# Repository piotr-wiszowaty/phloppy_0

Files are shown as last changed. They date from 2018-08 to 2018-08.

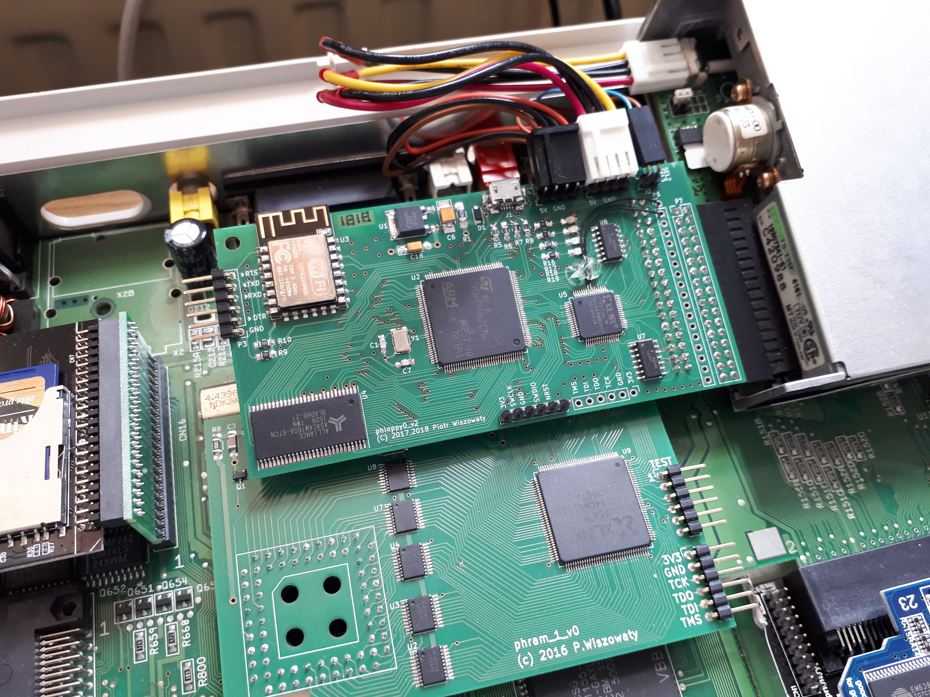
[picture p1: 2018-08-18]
photos/on_floppy.jpg

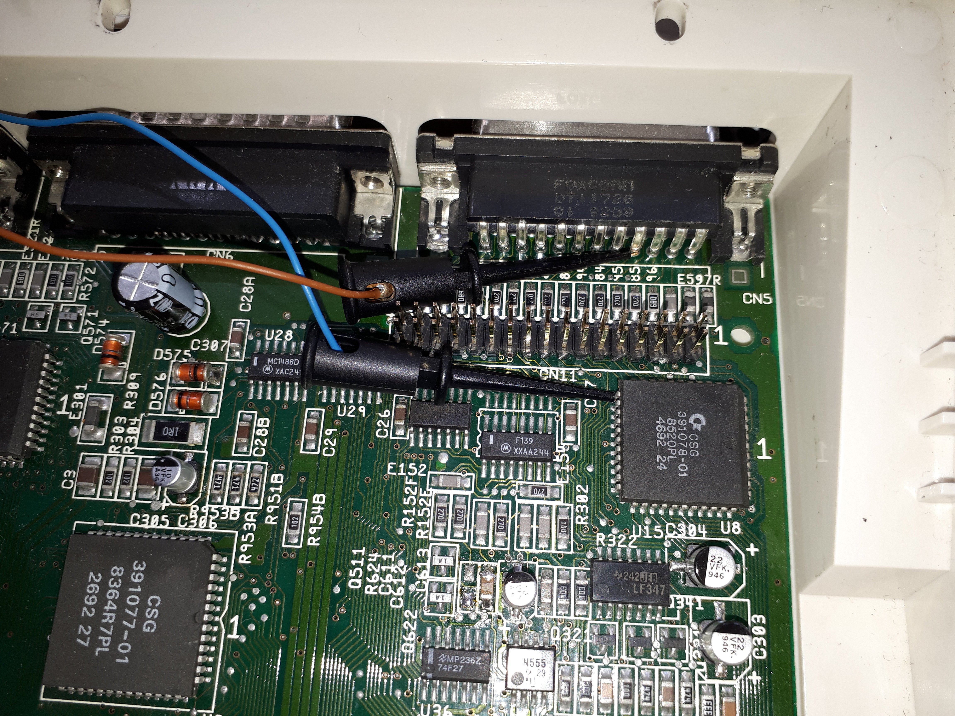
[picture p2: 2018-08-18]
photos/sel2_sel3_a.jpg

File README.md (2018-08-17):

phloppy\_0
=========

phloppy\_0 is a [Commodore Amiga](https://en.wikipedia.org/wiki/Amiga) floppy
drive emulator. It emulates four drives (`DF0:`, `DF1:`, `DF2:`, `DF3:`) and
is controlled through WiFi by an Android or a PC application.

`DF0:` - `DF3:` interoperation
--------------------------

The device is connected between the Amiga motherboard and the internal floppy
drive (DF0:). When a floppy image is inserted in the virtual DF0: the physical
drive input signals `SEL0` and `MTR0` are inactive. When there is no floppy image
in the virtual DF0: the `SEL0` and `MTR0` signals are passed from the Amiga
motherboard through the emulator to the physical drive.

When there are `DF1:` - `DF3`: physical drives connected to the Amiga, inserting
a floppy image in any of the virtual `DF1:` - `DF3:` will result in malfunction
of the drive.

Supported floppy image formats
------------------------------
 
Two floppy image formats are supported:
- ADF ([Amiga Disk File](https://en.wikipedia.org/wiki/Amiga\_Disk\_File)), 880 kB
- raw MFM - 12668 bytes per track, 160 tracks per disk

Hardware
--------

Main hardware components:
- STM32F446 - Cortex-M4 microcontroller; core of the emulator
- SDRAM, 8 MB; used for keeping floppy image contents
- ESP12-E - ESP8266 based WiFi module; provides WiFi hotspot to allow connection
  of a controlling application
- XC9272XL CPLD & two 8-channel open-drain buffers - interface between the
  microcontroller and the Amiga motherboard

On-board connectors:
- micro USB - for flashing the microcontroller
- SWD - for flashing/debugging the microcontroller
- JTAG - for flashing the CPLD
- UART (3.3 V) - for flashing the ESP8266
- power input - from the Amiga motherboard
- power output - to the physical floppy drive
- SEL2, SEL3 - input for the appropriate floppy selection signals
- male 34-pin pinheader - for connecting through a ribbon cable with
  the Amiga motherboard; for A600 the cable should be around 155 mm long
- female 34-pin pinheader - for connecting directly to the physical floppy
  drive

LEDs:
- green - indicates SDRAM active
- yellow - indicates read operation in progress
- red - indicates communication with the controlling application
  in progress
- blue - indicates write buffer is not empty (turn on the controlling
  application to write the buffer to the persistent memory)

In idle mode the device consumes around 170 mA. When the SDRAM is in active
mode the current consumption is around 185 mA.

Software
--------

Software components:
- `android/` - Android control application sources
- `cpld/` - CPLD design files
- `output/` - APK, JED, Gerbers, microcontroller firmware
- `pc/` - PC control application sources
- `uc/` - microcontroller firmware sources
- `wifi/` - ESP8266 source files

The Android application requires SDK level 15 and works at least on
Android 4.0.3 and 8.0.0.

The WiFi hotspot parameters are stored in the STM32 microcontroller and
read by ESP8266 during initialization. The parameters can be changed in source
code or after compilation in the microcontroller firmware image file.

License
-------

The project is licensed under GPL-3.0 license. See `LICENSE` for more information.
Parts of the project are covered by other licenses (see appropriate files for details):
- ESP8266 SPI driver by David Ogilvy (MetalPhreak)
- CMSIS header files by ARM LIMITED
- STM32 header files by STMicroelectronics

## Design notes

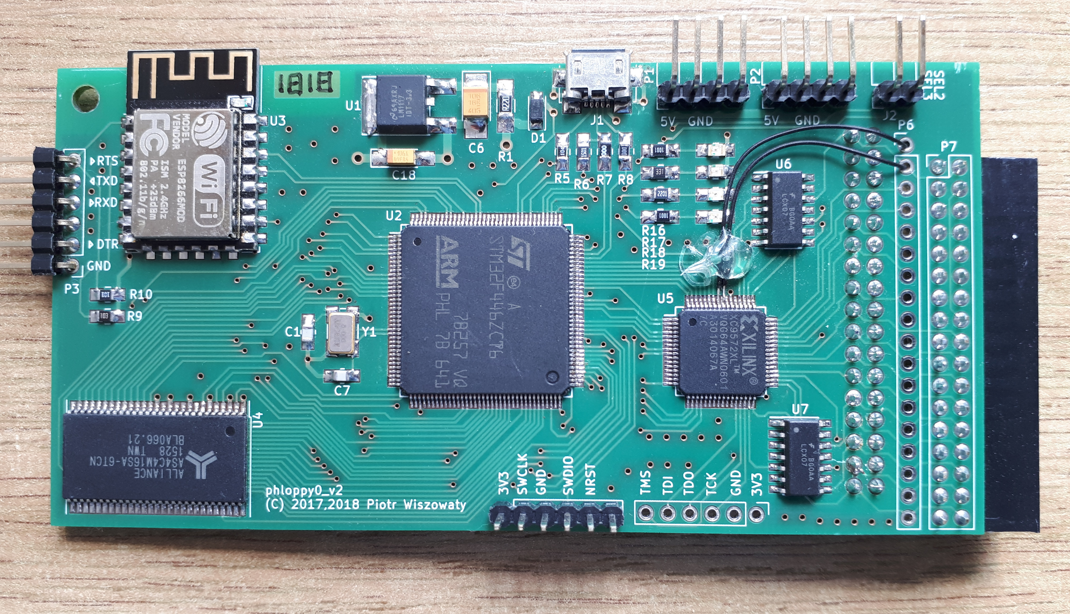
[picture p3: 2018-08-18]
photos/top.jpg

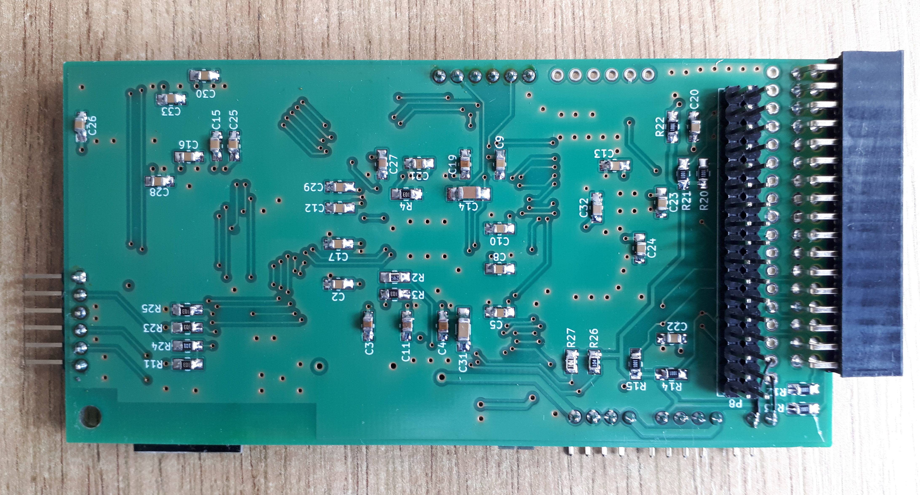
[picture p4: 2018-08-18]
photos/bottom.jpg

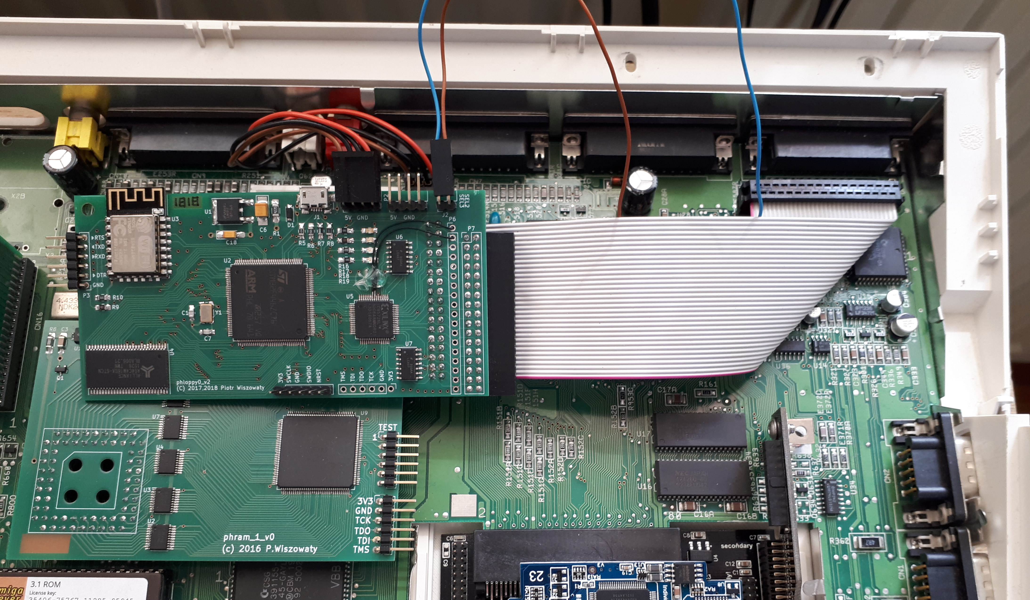
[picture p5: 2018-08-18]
photos/no_floppy.jpg

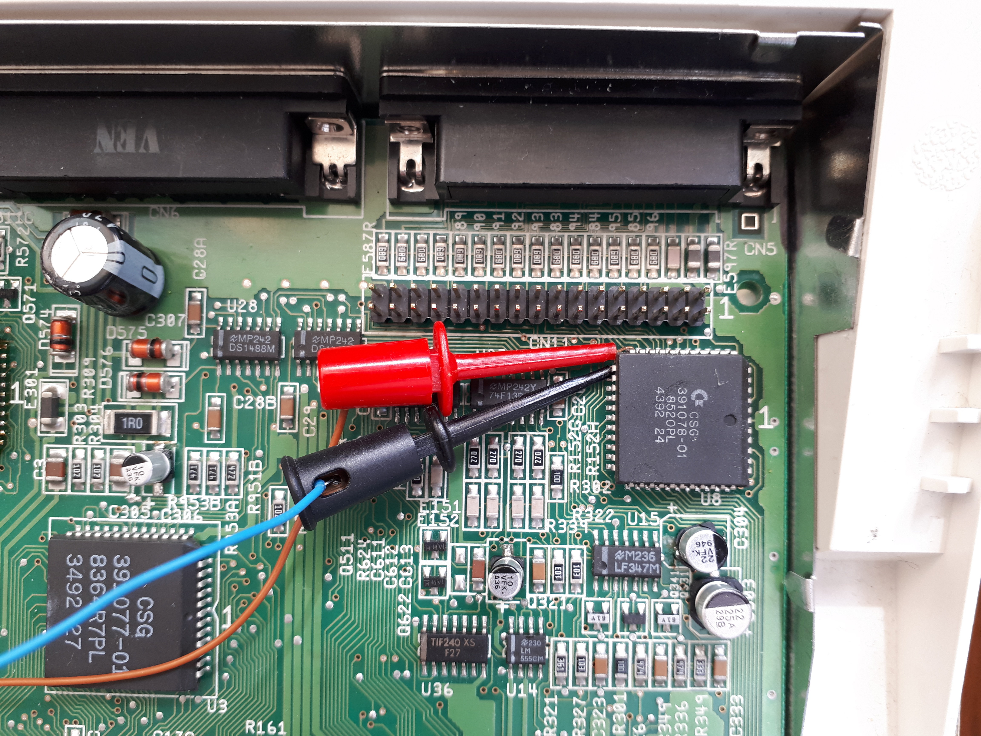
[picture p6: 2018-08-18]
photos/sel2_sel3_b.jpg

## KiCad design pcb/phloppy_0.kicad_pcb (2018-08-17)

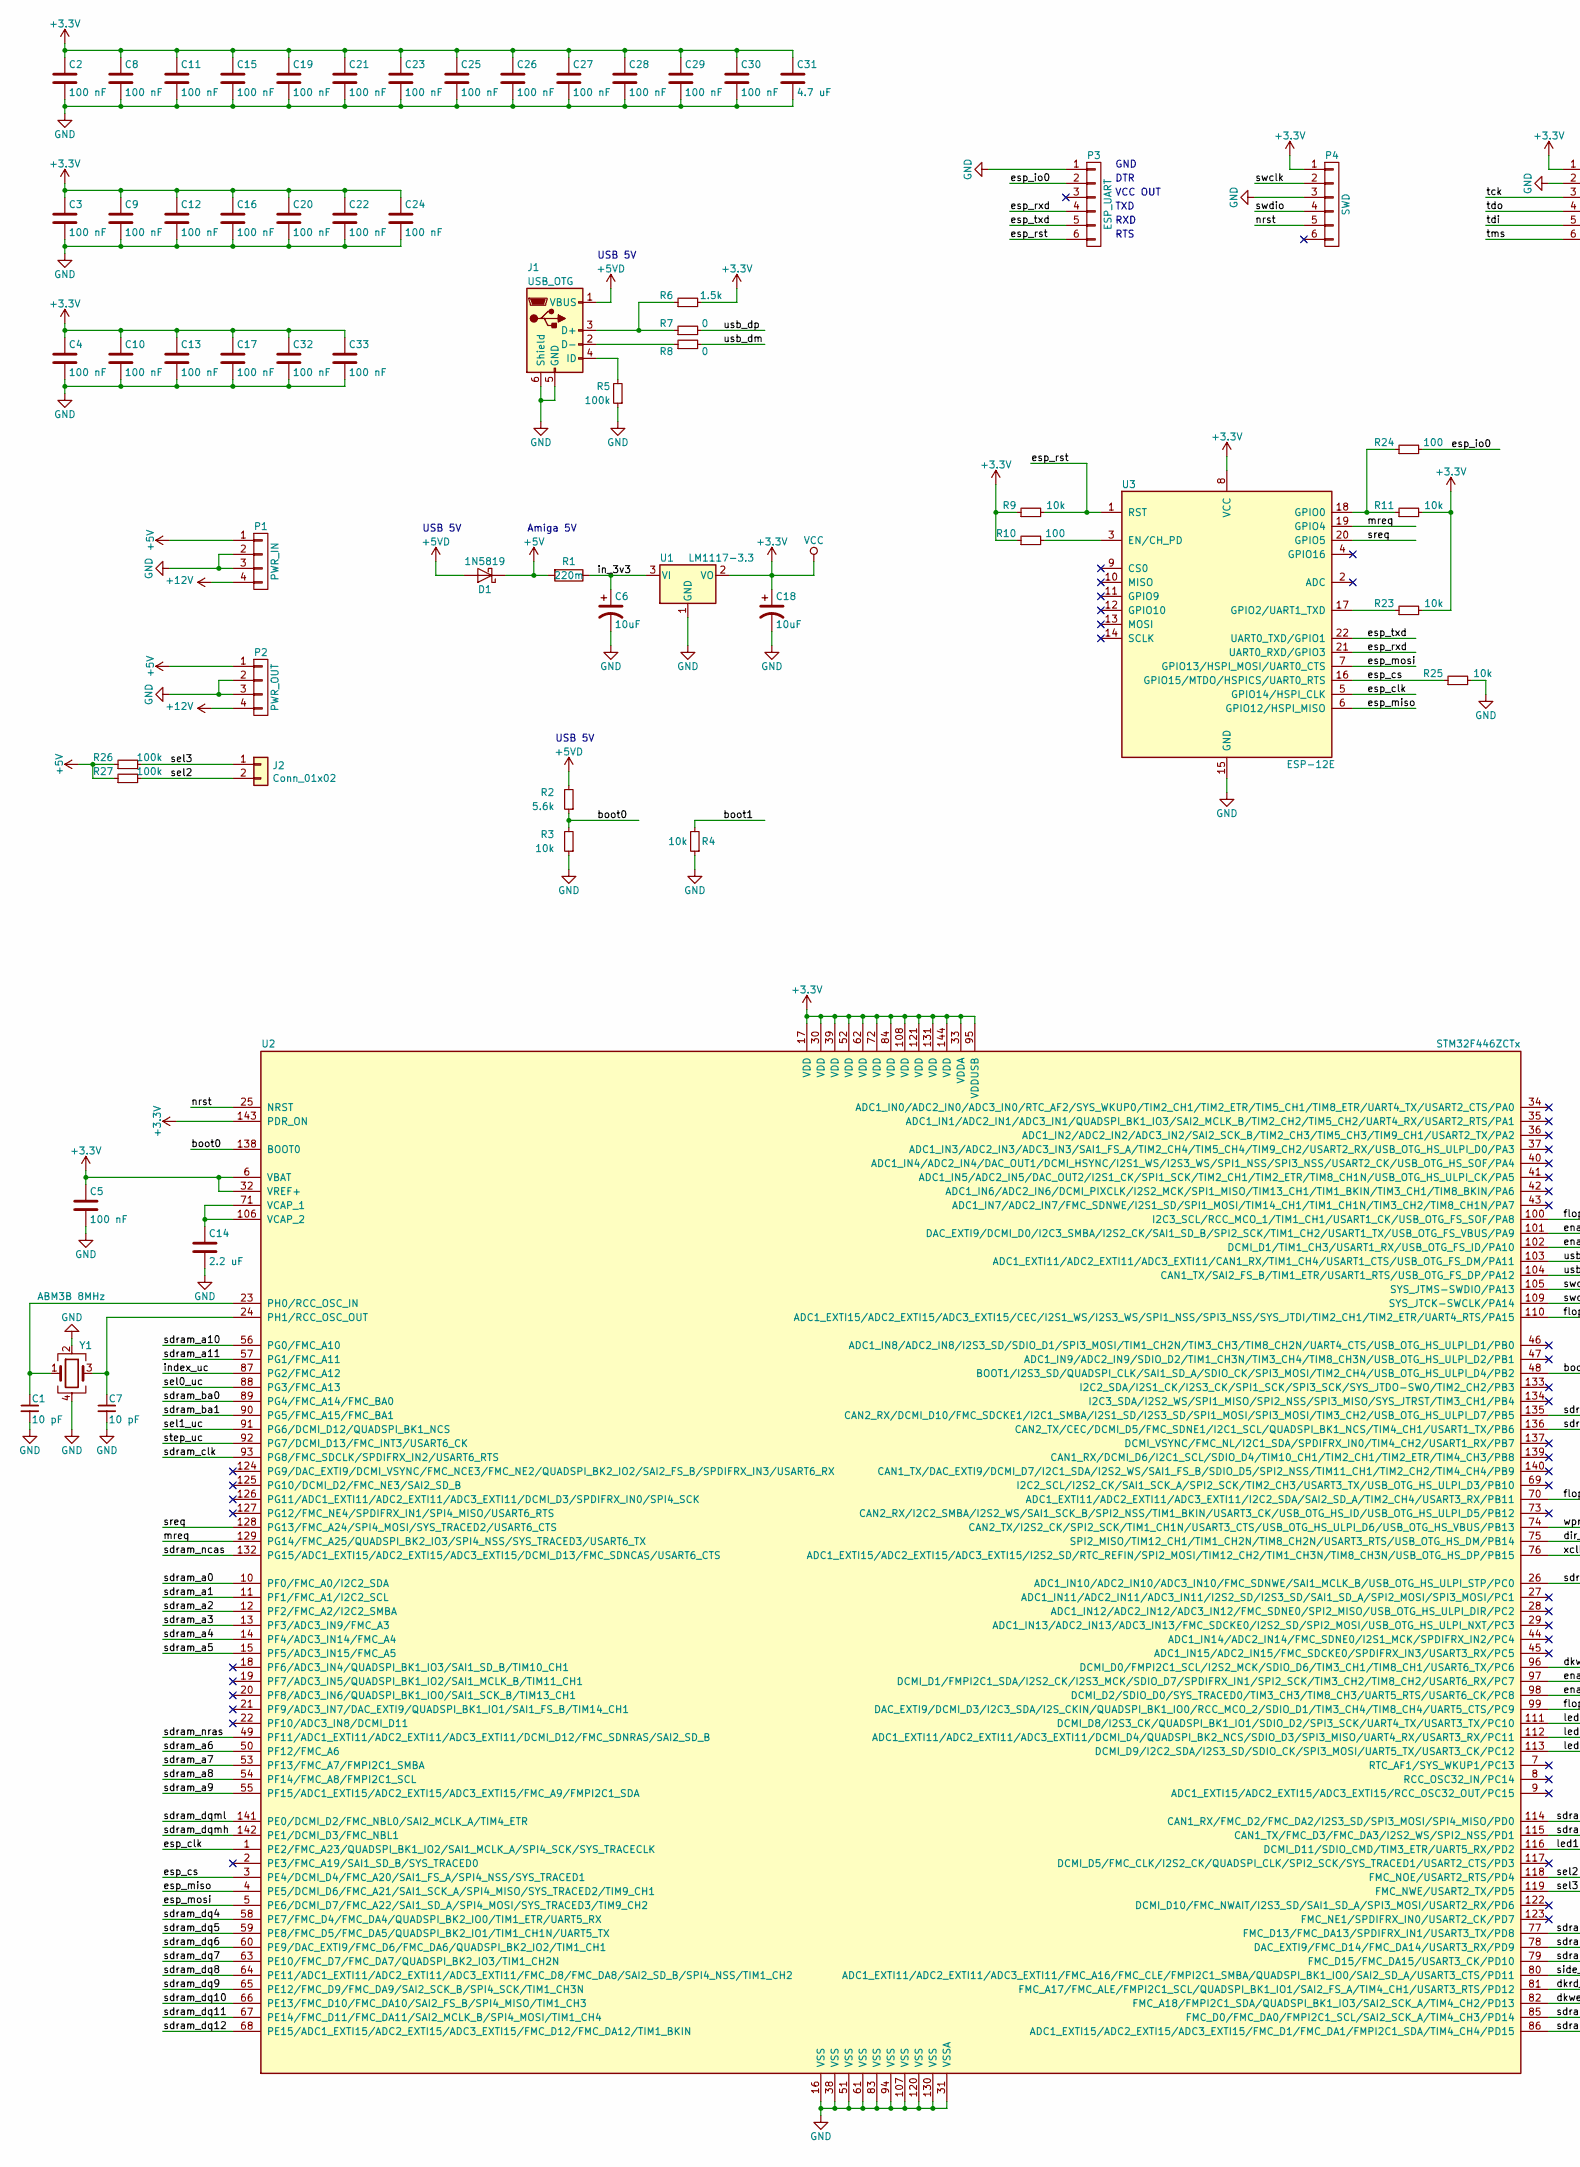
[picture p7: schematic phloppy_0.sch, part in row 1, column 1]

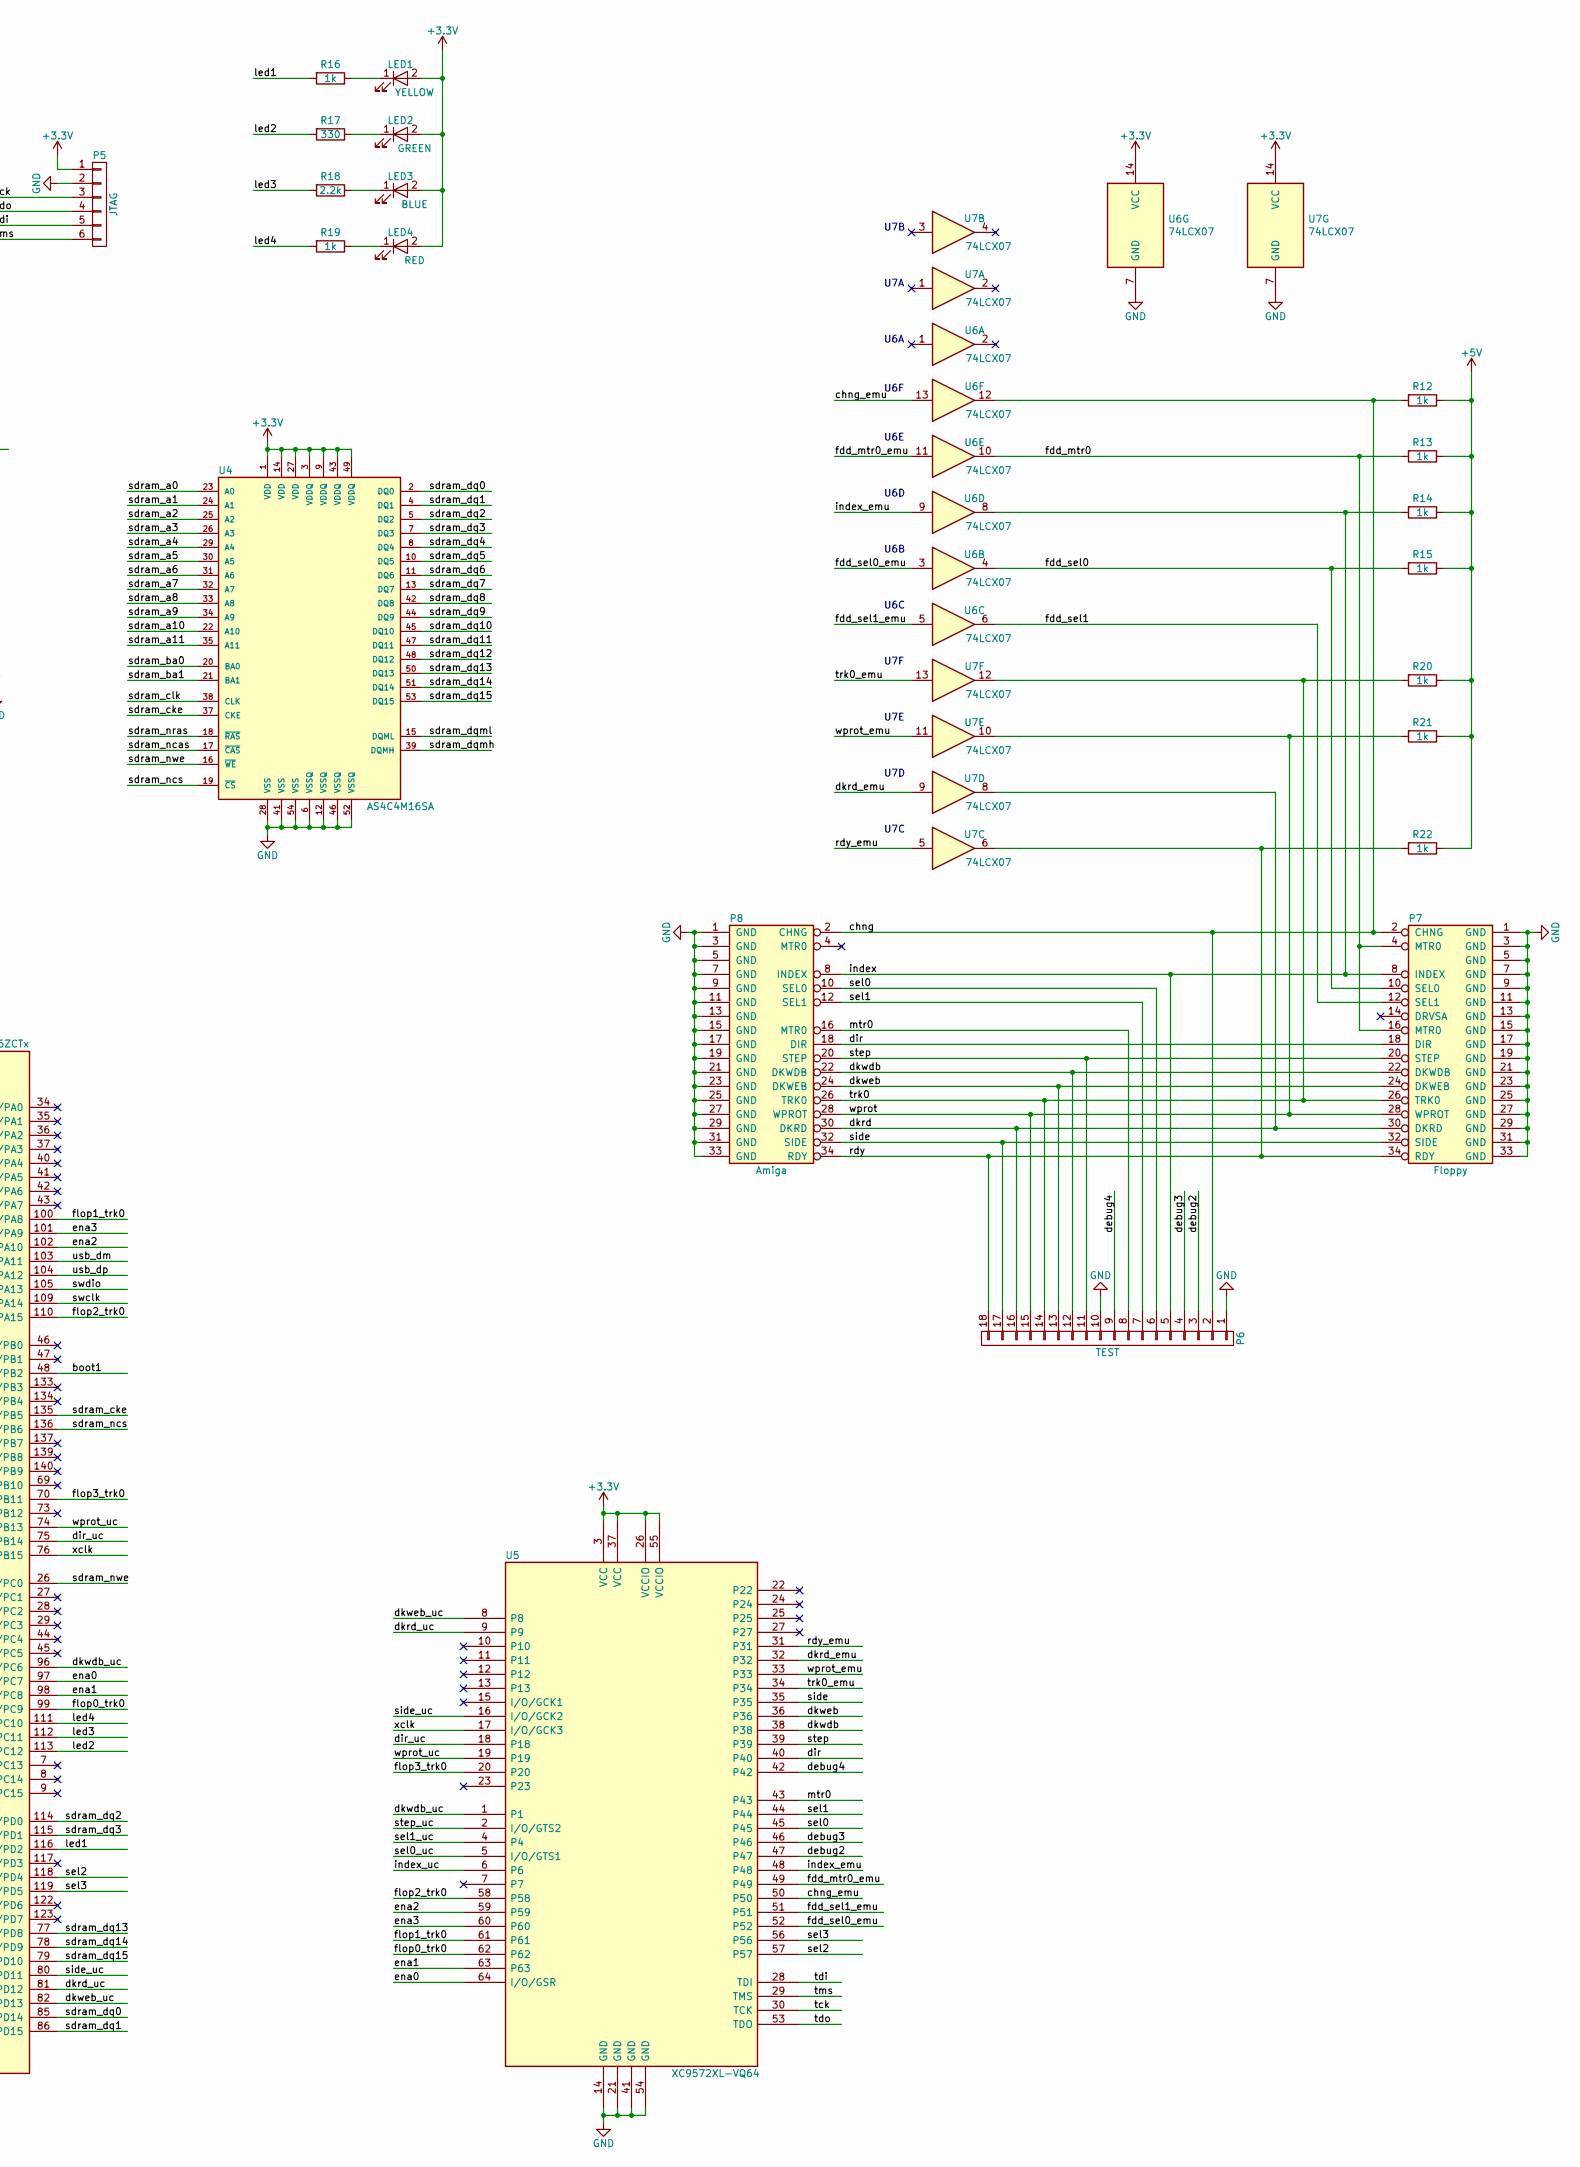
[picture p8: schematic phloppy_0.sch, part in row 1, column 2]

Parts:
C1, C7: 10 pF; C_0805_HandSoldering
C2, C3, C4, C5, C8, C9, C10, C11, C12, C13, C15, C16, C17, C19, C20, C21, C22, C23, C24, C25, C26, C27, C28, C29, C30, C32, C33: 100 nF; C_0805_HandSoldering
C6: 10uF; CP_Tantalum_Case-B_EIA-3528-21_Hand
C14: 2.2 uF; C_1206_HandSoldering
C18: 10uF; Tantalum_Case-A_EIA-3216-18_Hand
C31: 4.7 uF; C_1206_HandSoldering
D1: 1N5819; D_SOD-123
J1: USB_OTG; USB_Micro-B_Molex_47346-0001
J2: Conn_01x02; Pin_Header_Angled_1x02_Pitch2.54mm
LED1: YELLOW; LED_0805_HandSoldering
LED2: GREEN; LED_0805_HandSoldering
LED3: BLUE; LED_0805_HandSoldering
LED4: RED; LED_0805_HandSoldering
P1: PWR_IN; Pin_Header_Angled_1x04_Pitch2.54mm
P2: PWR_OUT; Pin_Header_Angled_1x04_Pitch2.54mm
P3: ESP_UART; Pin_Header_Straight_1x06_Pitch2.54mm
P4: SWD; Pin_Header_Straight_1x06_Pitch2.54mm
P5: JTAG; Pin_Header_Straight_1x06_Pitch2.54mm
P6: TEST; Pin_Header_Straight_1x18_Pitch2.54mm
P7: Floppy; Pin_Header_Straight_2x17_Pitch2.54mm
P8: Amiga; Pin_Header_Straight_2x17_Pitch2.54mm
R1: 220m; R_1206_HandSoldering
R2: 5.6k; R_0805_HandSoldering
R3, R4, R9, R11, R23, R25: 10k; R_0805_HandSoldering
R5: 100k; R_0805_HandSoldering
R6: 1.5k; R_0805_HandSoldering
R7, R8: 0; R_0805_HandSoldering
R10, R24: 100; R_0805_HandSoldering
R12, R13, R14, R15, R16, R19, R20, R21, R22: 1k; R_0805_HandSoldering
R17: 330; R_0805_HandSoldering
R18: 2.2k; R_0805_HandSoldering
R26, R27: 100k; R_0805_2012Metric_Pad1.15x1.50mm_HandSolder
U1: LM1117-3.3; TO-252-2Lead
U2: STM32F446ZCTx; LQFP-144_20x20mm_Pitch0.5mm
U3: ESP-12E
U4: AS4C4M16SA; TSOP-II-54_22.22x10.16mm_Pitch0.8mm
U5: XC9572XL-VQ64; TQFP-64_10x10mm_Pitch0.5mm
U6, U7: 74LCX07; SOIC-14_3.9x8.7mm_Pitch1.27mm
Y1: ABM3B 8MHz; Crystal_SMD_Abracon_ABM3B-4pin_5.0x3.2mm

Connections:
+3V3: C2.1, C3.1, C4.1, C5.1, C8.1, C9.1, C10.1, C11.1, C12.1, C13.1, C15.1, C16.1, C17.1, C18.1, C19.1, C20.1, C21.1, C22.1, C23.1, C24.1, C25.1, C26.1, C27.1, C28.1, C29.1, C30.1, C31.1, C32.1, C33.1, LED1.2 (A), LED2.2 (A), LED3.2 (A), LED4.2 (A), P4.1, P5.1, R6.2, R9.1, R10.1, R11.2, R23.2, U1.2 (VO), U2.6 (VBAT), U2.17 (VDD), U2.30 (VDD), U2.32 (VREF+), U2.33 (VDDA), U2.39 (VDD), U2.52 (VDD), U2.62 (VDD), U2.72 (VDD), U2.84 (VDD), U2.95 (VDDUSB), U2.108 (VDD), U2.121 (VDD), U2.131 (VDD), U2.143 (PDR_ON), U2.144 (VDD), U3.8 (VCC), U4.1 (VDD), U4.3 (VDDQ), U4.9 (VDDQ), U4.14 (VDD), U4.27 (VDD), U4.43 (VDDQ), U4.49 (VDDQ), U5.3 (VCC), U5.26 (VCCIO), U5.37 (VCC), U5.55 (VCCIO), U6.14 (VCC), U7.14 (VCC)
+5V: D1.1 (K), P1.1, P2.1, R1.2, R12.1, R13.1, R14.1, R15.1, R20.1, R21.1, R22.1, R26.1, R27.1
+5VD: D1.2 (A), J1.1 (VBUS), R2.2
+12V: P1.4, P2.4
/boot0: R2.1, R3.2, U2.138 (BOOT0)
/boot1: R4.2, U2.48 (BOOT1/I2S3_SD/QUADSPI_CLK/SAI1_SD_A/SDI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)
/chng: P6.2, P7.2 (CHNG), P8.2 (CHNG), R12.2, U6.12
/chng_emu: U5.50, U6.13
/debug2: P6.3, U5.47
/debug3: P6.4, U5.46
/debug4: P6.9, U5.42
/dir: P7.18 (DIR), P8.18 (DIR), U5.40
/dir_uc: U2.75 (SPI2_MISO/TIM12_CH1/TIM1_CH2N/TIM8_CH2N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), U5.18
/dkrd: P6.16, P7.30 (DKRD), P8.30 (DKRD), U7.8
/dkrd_emu: U5.32, U7.9
/dkrd_uc: U2.81 (FMC_A17/FMC_ALE/FMPI2C1_SCL/QUADSPI_BK1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), U5.9
/dkwdb: P6.12, P7.22 (DKWDB), P8.22 (DKWDB), U5.38
/dkwdb_uc: U2.96 (DCMI_D0/FMPI2C1_SCL/I2S2_MCK/SDIO_D6/TI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), U5.1
/dkweb: P6.13, P7.24 (DKWEB), P8.24 (DKWEB), U5.36
/dkweb_uc: U2.82 (FMC_A18/FMPI2C1_SDA/QUADSPI_BK1_IO3/SAI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), U5.8
/ena0: U2.97 (DCMI_D1/FMPI2C1_SDA/I2S2_CK/I2S3_MCK/SD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), U5.64 (I/O/GSR)
/ena1: U2.98 (DCMI_D2/SDIO_D0/SYS_TRACED0/TIM3_CH3/TI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), U5.63
/ena2: U2.102 (DCMI_D1/TIM1_CH3/USART1_RX/USB_OTG_FS_I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), U5.59
/ena3: U2.101 (DAC_EXTI9/DCMI_D0/I2C3_SMBA/I2S2_CK/SAI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), U5.60
/esp_clk: U2.1 (PE2/FMC_A23/QUADSPI_BK1_IO2/SAI1_MCLK_A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), U3.5 (GPIO14/HSPI_CLK)
/esp_cs: R25.1, U2.3 (PE4/DCMI_D4/FMC_A20/SAI1_FS_A/SPI4_NSS/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), U3.16 (GPIO15/MTDO/HSPICS/UART0_RTS)
/esp_io0: P3.2, R24.2
/esp_miso: U2.4 (PE5/DCMI_D6/FMC_A21/SAI1_SCK_A/SPI4_MIS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), U3.6 (GPIO12/HSPI_MISO)
/esp_mosi: U2.5 (PE6/DCMI_D7/FMC_A22/SAI1_SD_A/SPI4_MOSI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), U3.7 (GPIO13/HSPI_MOSI/UART0_CTS)
/esp_rst: P3.6, R9.2, U3.1 (RST)
/esp_rxd: P3.4, U3.21 (UART0_RXD/GPIO3)
/esp_txd: P3.5, U3.22 (UART0_TXD/GPIO1)
/fdd_mtr0: P7.4 (MTR0), P7.16 (MTR0), R13.2, U6.10
/fdd_mtr0_emu: U5.49, U6.11
/fdd_sel0: P7.10 (SEL0), R15.2, U6.4
/fdd_sel0_emu: U5.52, U6.3
/fdd_sel1: P7.12 (SEL1), U6.6
/fdd_sel1_emu: U5.51, U6.5
/flop0_trk0: U2.99 (DAC_EXTI9/DCMI_D3/I2C3_SDA/I2S_CKIN/QUA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), U5.62
/flop1_trk0: U2.100 (I2C3_SCL/RCC_MCO_1/TIM1_CH1/USART1_CK/U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), U5.61
/flop2_trk0: U2.110 (ADC1_EXTI15/ADC2_EXTI15/ADC3_EXTI15/CEC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), U5.58
/flop3_trk0: U2.70 (ADC1_EXTI11/ADC2_EXTI11/ADC3_EXTI11/I2C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), U5.20
/in_3v3: C6.1, R1.1, U1.3 (VI)
/index: P6.5, P7.8 (INDEX), P8.8 (INDEX), R14.2, U6.8
/index_emu: U5.48, U6.9
/index_uc: U2.87 (PG2/FMC_A12), U5.6
/led1: R16.2, U2.116 (DCMI_D11/SDIO_CMD/TIM3_ETR/UART5_RX/PD2)
/led2: R17.2, U2.113 (DCMI_D9/I2C2_SDA/I2S3_SD/SDIO_CK/SPI3_M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)
/led3: R18.2, U2.112 (ADC1_EXTI11/ADC2_EXTI11/ADC3_EXTI11/DCM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)
/led4: R19.2, U2.111 (DCMI_D8/I2S3_CK/QUADSPI_BK1_IO1/SDIO_D2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)
/mreq: U2.129 (PG14/FMC_A25/QUADSPI_BK2_IO3/SPI4_NSS/S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), U3.19 (GPIO4)
/mtr0: P6.8, P8.16 (MTR0), U5.43
/nrst: P4.5, U2.25 (NRST)
/rdy: P6.18, P7.34 (RDY), P8.34 (RDY), R22.2, U7.6
/rdy_emu: U5.31, U7.5
/sdram_a0: U2.10 (PF0/FMC_A0/I2C2_SDA), U4.23 (A0)
/sdram_a1: U2.11 (PF1/FMC_A1/I2C2_SCL), U4.24 (A1)
/sdram_a2: U2.12 (PF2/FMC_A2/I2C2_SMBA), U4.25 (A2)
/sdram_a3: U2.13 (PF3/ADC3_IN9/FMC_A3), U4.26 (A3)
/sdram_a4: U2.14 (PF4/ADC3_IN14/FMC_A4), U4.29 (A4)
/sdram_a5: U2.15 (PF5/ADC3_IN15/FMC_A5), U4.30 (A5)
/sdram_a6: U2.50 (PF12/FMC_A6), U4.31 (A6)
/sdram_a7: U2.53 (PF13/FMC_A7/FMPI2C1_SMBA), U4.32 (A7)
/sdram_a8: U2.54 (PF14/FMC_A8/FMPI2C1_SCL), U4.33 (A8)
/sdram_a9: U2.55 (PF15/ADC1_EXTI15/ADC2_EXTI15/ADC3_EXTI1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), U4.34 (A9)
/sdram_a10: U2.56 (PG0/FMC_A10), U4.22 (A10)
/sdram_a11: U2.57 (PG1/FMC_A11), U4.35 (A11)
/sdram_ba0: U2.89 (PG4/FMC_A14/FMC_BA0), U4.20 (BA0)
/sdram_ba1: U2.90 (PG5/FMC_A15/FMC_BA1), U4.21 (BA1)
/sdram_cke: U2.135 (CAN2_RX/DCMI_D10/FMC_SDCKE1/I2C1_SMBA/I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), U4.37 (CKE)
/sdram_clk: U2.93 (PG8/FMC_SDCLK/SPDIFRX_IN2/USART6_RTS), U4.38 (CLK)
/sdram_dq0: U2.85 (FMC_D0/FMC_DA0/FMPI2C1_SCL/SAI2_SCK_A/T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), U4.2 (DQ0)
/sdram_dq1: U2.86 (ADC1_EXTI15/ADC2_EXTI15/ADC3_EXTI15/FMC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), U4.4 (DQ1)
/sdram_dq2: U2.114 (CAN1_RX/FMC_D2/FMC_DA2/I2S3_SD/SPI3_MOS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), U4.5 (DQ2)
/sdram_dq3: U2.115 (CAN1_TX/FMC_D3/FMC_DA3/I2S2_WS/SPI2_NSS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), U4.7 (DQ3)
/sdram_dq4: U2.58 (PE7/FMC_D4/FMC_DA4/QUADSPI_BK2_IO0/TIM1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), U4.8 (DQ4)
/sdram_dq5: U2.59 (PE8/FMC_D5/FMC_DA5/QUADSPI_BK2_IO1/TIM1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), U4.10 (DQ5)
/sdram_dq6: U2.60 (PE9/DAC_EXTI9/FMC_D6/FMC_DA6/QUADSPI_BK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), U4.11 (DQ6)
/sdram_dq7: U2.63 (PE10/FMC_D7/FMC_DA7/QUADSPI_BK2_IO3/TIM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), U4.13 (DQ7)
/sdram_dq8: U2.64 (PE11/ADC1_EXTI11/ADC2_EXTI11/ADC3_EXTI1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), U4.42 (DQ8)
/sdram_dq9: U2.65 (PE12/FMC_D9/FMC_DA9/SAI2_SCK_B/SPI4_SCK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), U4.44 (DQ9)
/sdram_dq10: U2.66 (PE13/FMC_D10/FMC_DA10/SAI2_FS_B/SPI4_MI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), U4.45 (DQ10)
/sdram_dq11: U2.67 (PE14/FMC_D11/FMC_DA11/SAI2_MCLK_B/SPI4_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), U4.47 (DQ11)
/sdram_dq12: U2.68 (PE15/ADC1_EXTI15/ADC2_EXTI15/ADC3_EXTI1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), U4.48 (DQ12)
/sdram_dq13: U2.77 (FMC_D13/FMC_DA13/SPDIFRX_IN1/USART3_TX/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), U4.50 (DQ13)
/sdram_dq14: U2.78 (DAC_EXTI9/FMC_D14/FMC_DA14/USART3_RX/PD9), U4.51 (DQ14)
/sdram_dq15: U2.79 (FMC_D15/FMC_DA15/USART3_CK/PD10), U4.53 (DQ15)
/sdram_dqmh: U2.142 (PE1/DCMI_D3/FMC_NBL1), U4.39 (DQMH)
/sdram_dqml: U2.141 (PE0/DCMI_D2/FMC_NBL0/SAI2_MCLK_A/TIM4_E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), U4.15 (DQML)
/sdram_ncas: U2.132 (PG15/ADC1_EXTI15/ADC2_EXTI15/ADC3_EXTI1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), U4.17 (~CAS~)
/sdram_ncs: U2.136 (CAN2_TX/CEC/DCMI_D5/FMC_SDNE1/I2C1_SCL/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), U4.19 (~CS~)
/sdram_nras: U2.49 (PF11/ADC1_EXTI11/ADC2_EXTI11/ADC3_EXTI1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), U4.18 (~RAS~)
/sdram_nwe: U2.26 (ADC1_IN10/ADC2_IN10/ADC3_IN10/FMC_SDNWE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), U4.16 (~WE~)
/sel0: P6.6, P8.10 (SEL0), U5.45
/sel0_uc: U2.88 (PG3/FMC_A13), U5.5 (I/O/GTS1)
/sel1: P6.7, P8.12 (SEL1), U5.44
/sel1_uc: U2.91 (PG6/DCMI_D12/QUADSPI_BK1_NCS), U5.4
/sel2: J2.2, R27.2, U2.118 (FMC_NOE/USART2_RTS/PD4), U5.57
/sel3: J2.1, R26.2, U2.119 (FMC_NWE/USART2_TX/PD5), U5.56
/side: P6.17, P7.32 (SIDE), P8.32 (SIDE), U5.35
/side_uc: U2.80 (ADC1_EXTI11/ADC2_EXTI11/ADC3_EXTI11/FMC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), U5.16 (I/O/GCK2)
/sreq: U2.128 (PG13/FMC_A24/SPI4_MOSI/SYS_TRACED2/USAR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), U3.20 (GPIO5)
/step: P6.11, P7.20 (STEP), P8.20 (STEP), U5.39
/step_uc: U2.92 (PG7/DCMI_D13/FMC_INT3/USART6_CK), U5.2 (I/O/GTS2)
/swclk: P4.2, U2.109 (SYS_JTCK-SWCLK/PA14)
/swdio: P4.4, U2.105 (SYS_JTMS-SWDIO/PA13)
/tck: P5.3, U5.30 (TCK)
/tdi: P5.5, U5.28 (TDI)
/tdo: P5.4, U5.53 (TDO)
/tms: P5.6, U5.29 (TMS)
/trk0: P6.14, P7.26 (TRK0), P8.26 (TRK0), R20.2, U7.12
/trk0_emu: U5.34, U7.13
/usb_dm: R8.2, U2.103 (ADC1_EXTI11/ADC2_EXTI11/ADC3_EXTI11/CAN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)
/usb_dp: R7.2, U2.104 (CAN1_TX/SAI2_FS_B/TIM1_ETR/USART1_RTS/U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)
/wprot: P6.15, P7.28 (WPROT), P8.28 (WPROT), R21.2, U7.10
/wprot_emu: U5.33, U7.11
/wprot_uc: U2.74 (CAN2_TX/I2S2_CK/SPI2_SCK/TIM1_CH1N/USAR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), U5.19
/xclk: U2.76 (ADC1_EXTI15/ADC2_EXTI15/ADC3_EXTI15/I2S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), U5.17 (I/O/GCK3)
GND: C1.2, C2.2, C3.2, C4.2, C5.2, C6.2, C7.2, C8.2, C9.2, C10.2, C11.2, C12.2, C13.2, C14.2, C15.2, C16.2, C17.2, C18.2, C19.2, C20.2, C21.2, C22.2, C23.2, C24.2, C25.2, C26.2, C27.2, C28.2, C29.2, C30.2, C31.2, C32.2, C33.2, J1.5 (GND), J1.6 (Shield), P1.2, P1.3, P2.2, P2.3, P3.1, P4.3, P5.2, P6.1, P6.10, P7.1 (GND), P7.3 (GND), P7.5 (GND), P7.7 (GND), P7.9 (GND), P7.11 (GND), P7.13 (GND), P7.15 (GND), P7.17 (GND), P7.19 (GND), P7.21 (GND), P7.23 (GND), P7.25 (GND), P7.27 (GND), P7.29 (GND), P7.31 (GND), P7.33 (GND), P8.1 (GND), P8.3 (GND), P8.5 (GND), P8.7 (GND), P8.9 (GND), P8.11 (GND), P8.13 (GND), P8.15 (GND), P8.17 (GND), P8.19 (GND), P8.21 (GND), P8.23 (GND), P8.25 (GND), P8.27 (GND), P8.29 (GND), P8.31 (GND), P8.33 (GND), R3.1, R4.1, R5.1, R25.2, U1.1 (GND), U2.16 (VSS), U2.31 (VSSA), U2.38 (VSS), U2.51 (VSS), U2.61 (VSS), U2.83 (VSS), U2.94 (VSS), U2.107 (VSS), U2.120 (VSS), U2.130 (VSS), U3.15 (GND), U4.6 (VSSQ), U4.12 (VSSQ), U4.28 (VSS), U4.41 (VSS), U4.46 (VSSQ), U4.52 (VSSQ), U4.54 (VSS), U5.14 (GND), U5.21 (GND), U5.41 (GND), U5.54 (GND), U6.7 (GND), U7.7 (GND), Y1.2, Y1.4
unnamed: C1.1, U2.23 (PH0/RCC_OSC_IN), Y1.1
unnamed: C7.1, U2.24 (PH1/RCC_OSC_OUT), Y1.3
unnamed: C14.1, U2.71 (VCAP_1), U2.106 (VCAP_2)
unnamed: J1.2 (D-), R8.1
unnamed: J1.3 (D+), R6.1, R7.1
unnamed: J1.4 (ID), R5.2
unnamed: LED1.1 (K), R16.1
unnamed: LED2.1 (K), R17.1
unnamed: LED3.1 (K), R18.1
unnamed: LED4.1 (K), R19.1
unnamed: R10.2, U3.3 (EN/CH_PD)
unnamed: R11.1, R24.1, U3.18 (GPIO0)
unnamed: R23.1, U3.17 (GPIO2/UART1_TXD)

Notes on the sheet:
USB 5V
Amiga 5V
DTR
VCC OUT
GND
TXD
RXD
RTS
U7B
U7A
U6A
U6F
U6E
U6D
U6B
U6C
U7F
U7E
U7D
U7C

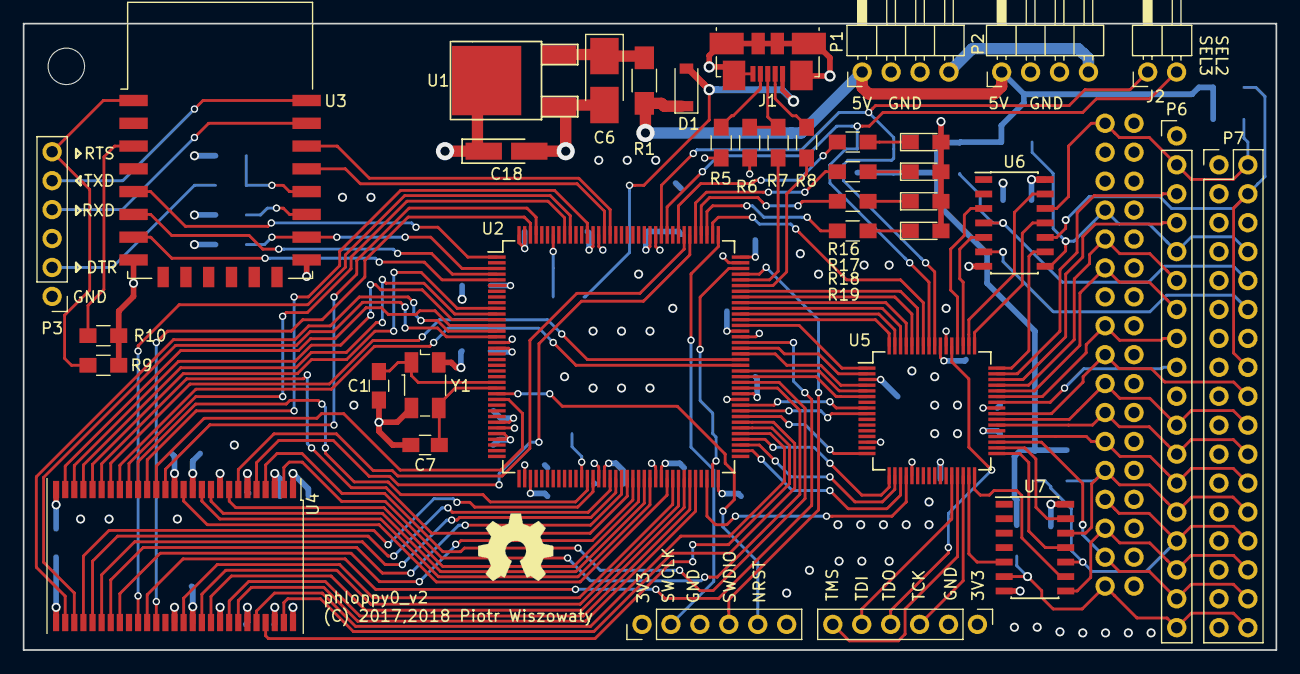
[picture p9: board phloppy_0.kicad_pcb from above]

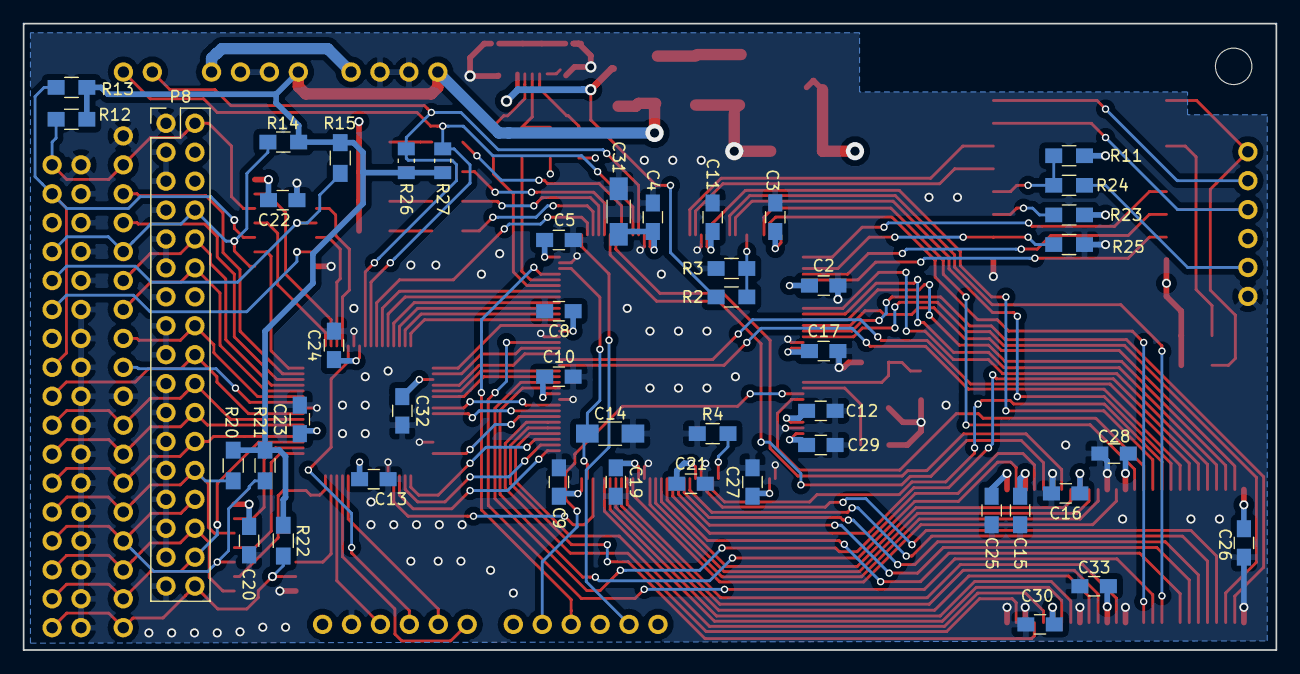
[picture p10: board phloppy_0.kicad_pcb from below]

Board: 4 copper layers, 110.0 x 55.0 mm, 83 parts (46 on the bottom side), 132 nets.

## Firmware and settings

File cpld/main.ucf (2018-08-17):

net "dkweb_uc" loc = p8;
net "dkrd_uc" loc = p9;
net "side_uc" loc = p16;
net "xclk" loc = p17;
net "dir_uc" loc = p18;
net "wprot_uc" loc = p19;
net "dkwdb_uc" loc = p1;
net "step_uc" loc = p2;
net "sel1_uc" loc = p4;
net "sel0_uc" loc = p5;
net "index_uc" loc = p6;
net "flop2_trk0" loc = p58;
net "flop3_trk0" loc = p20;
net "ena2" loc = p59;
net "ena3" loc = p60;
net "flop1_trk0" loc = p61;
net "flop0_trk0" loc = p62;
net "ena1" loc = p63;
net "ena0" loc = p64;
net "rdy_emu" loc = p31;
net "dkrd_emu" loc = p32;
net "wprot_emu" loc = p33;
net "trk0_emu" loc = p34;
net "side" loc = p35;
net "dkweb" loc = p36;
net "dkwdb" loc = p38;
net "step" loc = p39;
net "dir" loc = p40;
net "debug4" loc = p42;
net "mtr0" loc = p43;
net "sel3" loc = p56;
net "sel2" loc = p57;
net "sel1" loc = p44;
net "sel0" loc = p45;
net "debug3" loc = p46;
net "debug2" loc = p47;
net "index_emu" loc = p48;
net "fdd_mtr0_emu" loc = p49;
net "chng_emu" loc = p50;
net "fdd_sel1_emu" loc = p51;
net "fdd_sel0_emu" loc = p52;

NET "xclk" BUFG = CLK;
NET "xclk" TNM_NET = xclk;
TIMESPEC TS_xclk = PERIOD "xclk" 10 MHz HIGH 50%;

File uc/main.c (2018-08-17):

/*
 * phloppy_0 - Commodore Amiga floppy drive emulator
 * Copyright (C) 2016-2018 Piotr Wiszowaty
 *
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
 * You should have received a copy of the GNU General Public License
 * along with this program.  If not, see <http://www.gnu.org/licenses/>.
 */

#include <stm32f446xx.h>
#include "fmc.h"
#include "wifi_parameters.h"

#ifndef VERSION
#error "VERSION undefined"
#endif
#if (VERSION != 0) && (VERSION != 2)
#error "VERSION invalid (valid: 0, 2)"
#endif

// [long word]
#define RAW_TRACK_SIZE	(12668/4)

// [long word]
#define MFM_TRACK_SIZE	(11*1088/4)
// [long word]
#define MFM_GAP_SIZE	(RAW_TRACK_SIZE - MFM_TRACK_SIZE)
#define READ_DELAY_US	10000

// [long word]
#define ADF_TRACK_SIZE	(512*11 / 4)

#define MAX_DIRTY_TTS	256

#define HCLK		160000000
#define PCLK1		40000000
#define TIM_PCLK1	(2*PCLK1)
#define PCLK2		80000000
#define TIM_PCLK2	(2*PCLK2)

#define TIM3_FREQ	10000
#define TIM4_FREQ	2000000
#define TIM5_FREQ	2000
#define TIM6_FREQ	1000000
#define TIM8_FREQ	10000000
#define TIM12_FREQ	10000000

// [100 us]
#define SDRAM_IDLE_TIME	50000

#define setup_pin(port, bit, mode, speed, altfun)									\
	GPIO##port->MODER = (GPIO##port->MODER & ~(3<<2*(bit))) | ((mode) << 2*(bit));					\
	GPIO##port->OSPEEDR = (GPIO##port->OSPEEDR & ~(3<<2*(bit))) | ((speed) << 2*(bit));				\
	GPIO##port->AFR[(bit)>>3] = (GPIO##port->AFR[(bit)>>3] & ~(15<<4*((bit)&7))) | (altfun << 4*((bit) & 7))

#define FLOPPY0_SEL	(GPIOG->IDR & (1 << SEL0))
#define FLOPPY1_SEL	(GPIOG->IDR & (1 << SEL1))
#define FLOPPY2_SEL	(GPIOD->IDR & (1 << SEL2))
#define FLOPPY3_SEL	(GPIOD->IDR & (1 << SEL3))

#define EMPTY_TRACK_MASK_FLOPPY0_HEAD0	0x01
#define EMPTY_TRACK_MASK_FLOPPY0_HEAD1	0x02
#define EMPTY_TRACK_MASK_FLOPPY1_HEAD0	0x04
#define EMPTY_TRACK_MASK_FLOPPY1_HEAD1	0x08
#define EMPTY_TRACK_MASK_FLOPPY2_HEAD0	0x10
#define EMPTY_TRACK_MASK_FLOPPY2_HEAD1	0x20
#define EMPTY_TRACK_MASK_FLOPPY3_HEAD0	0x40
#define EMPTY_TRACK_MASK_FLOPPY3_HEAD1	0x80

#define END		0xc0
#define ESC		0xdb
#define ESC_END		0xdc
#define ESC_ESC		0xdd

typedef enum {
	NOP,
	OP,
	TRANSMIT
} State;

typedef enum {
	SYNC_WORD,
	INFO_ODD,
	INFO_EVEN,
	LABEL_ODD,
	LABEL_EVEN,
	HDR_CHECKSUM_ODD,
	HDR_CHECKSUM_EVEN,
	DATA_CHECKSUM_ODD,
	DATA_CHECKSUM_EVEN,
	DATA_ODD,
	DATA_EVEN
} Decode_state;

#define OP_NOP		0x00
#define OP_INSERT0	0x01
#define OP_INSERT1	0x02
#define OP_EJECT0	0x03
#define OP_EJECT1	0x04
#define OP_FILL0	0x05
#define OP_FILL1	0x06
#define OP_WPROT0	0x07
#define OP_WPROT1	0x08
#define OP_WUNPROT0	0x09
#define OP_WUNPROT1	0x0a
#define OP_INSERT2	0x11
#define OP_INSERT3	0x12
#define OP_EJECT2	0x13
#define OP_EJECT3	0x14
#define OP_FILL2	0x15
#define OP_FILL3	0x16
#define OP_WPROT2	0x17
#define OP_WPROT3	0x18
#define OP_WUNPROT2	0x19
#define OP_WUNPROT3	0x1a
#define OP_TYPE0_ADF	0x1b
#define OP_TYPE1_ADF	0x1c
#define OP_TYPE2_ADF	0x1d
#define OP_TYPE3_ADF	0x1e
#define OP_TYPE0_RAW	0x1f
#define OP_TYPE1_RAW	0x20
#define OP_TYPE2_RAW	0x21
#define OP_TYPE3_RAW	0x22
#define OP_SETUP_WIFI	0x80

// PA
#define FLOP1_TRK0	8
#define ENA3		9
#define ENA2		10
#define FLOP2_TRK0	15

// PB
#define SDCKE1		5
#define SDNE1		6
#define FLOP3_TRK0	11
#define WPROT		13
#define DIR		14
#define XCLK		15

// PC
#define SDNWE		0
#define DKWDB		6
#define ENA0		7
#define ENA1		8
#define FLOP0_TRK0	9
#define LED_RED		10
#define LED_BLUE	11
#define LED_GREEN	12

// PD
#define SD_D2		0
#define SD_D3		1
#define LED_YELLOW	2
#define SEL2		4
#define SEL3		5
#define SD_D13		8
#define SD_D14		9
#define SD_D15		10
#define SIDE		11
#define DKRD		12
#define DKWEB		13
#define SD_D0		14
#define SD_D1		15

// PE
#define NBL0		0
#define NBL1		1
#define ESP_CLK		2
#define ESP_CS		4
#define ESP_MISO	5
#define ESP_MOSI	6
#define SD_D4		7
#define SD_D5		8
#define SD_D6		9
#define SD_D7		10
#define SD_D8		11
#define SD_D9		12
#define SD_D10		13
#define SD_D11		14
#define SD_D12		15

// PF
#define SD_A0		0
#define SD_A1		1
#define SD_A2		2
#define SD_A3		3
#define SD_A4		4
#define SD_A5		5
#define SDNRAS		11
#define SD_A6		12
#define SD_A7		13
#define SD_A8		14
#define SD_A9		15

// PG
#define SD_A10		0
#define SD_A11		1
#define INDEX		2
#define SEL0		3
#define BA0		4
#define BA1		5
#define SEL1		6
#define STEP		7
#define SDNCLK		8
#define SREQ		13
#define MREQ		14
#define SDNCAS		15

#if VERSION != 0
#define EXTI_SEL23_MSK	((1 << SEL2) | (1 << SEL3))
#else
#define EXTI_SEL23_MSK	0
#endif

const struct wifi_parameters wifi_parameters = {
	{192, 168, 4, 1},
	{255, 255, 255, 0},
	{192, 168, 4, 2},
	{192, 168, 4, 3},
	"Phloppy_0",
	"password_0"
};

const unsigned short dkrd_tim_arr_lut[] = {2*TIM4_FREQ/1000000-1, 4*TIM4_FREQ/1000000-1, 6*TIM4_FREQ/1000000-1, 8*TIM4_FREQ/1000000-1};

volatile int timer0 = 0;
volatile int timer1 = SDRAM_IDLE_TIME;

unsigned int mfm_track_floppy0_head0[RAW_TRACK_SIZE];
unsigned int mfm_track_floppy0_head1[RAW_TRACK_SIZE];
unsigned int mfm_track_floppy1_head0[RAW_TRACK_SIZE];
unsigned int mfm_track_floppy1_head1[RAW_TRACK_SIZE];
unsigned int mfm_track_floppy2_head0[RAW_TRACK_SIZE];
unsigned int mfm_track_floppy2_head1[RAW_TRACK_SIZE];
unsigned int mfm_track_floppy3_head0[RAW_TRACK_SIZE];
unsigned int mfm_track_floppy3_head1[RAW_TRACK_SIZE];
unsigned int *mfm_track = mfm_track_floppy0_head0;
volatile unsigned int current_mfm_long;
volatile unsigned int mfm_offset;
volatile unsigned int mfm_bitmask;
volatile unsigned int mfm_bitcount;
volatile unsigned int mfm_track_type;
volatile unsigned int received_sectors;
volatile unsigned int current_track_empty;
volatile unsigned int empty_tracks;
volatile Decode_state mfm_decode_state;
volatile int mfm_break;
volatile unsigned int floppy_type;					// 0: ADF, 1: raw
unsigned int *floppy0_data = (unsigned int *) 0xd0000000;
unsigned int *floppy1_data = (unsigned int *) 0xd0200000;
unsigned int *floppy2_data = (unsigned int *) 0xd0400000;
unsigned int *floppy3_data = (unsigned int *) 0xd0600000;
volatile int floppy0_current_cylinder;
volatile int floppy1_current_cylinder;
volatile int floppy2_current_cylinder;
volatile int floppy3_current_cylinder;
int floppy0_write_protected = 1;
int floppy1_write_protected = 1;
int floppy2_write_protected = 1;
int floppy3_write_protected = 1;
volatile unsigned int *written_track_start;
unsigned char floppy0_dirty_tts[MAX_DIRTY_TTS];				// (cylinder << 1) | head
unsigned char floppy1_dirty_tts[MAX_DIRTY_TTS];				// (cylinder << 1) | head
unsigned char floppy2_dirty_tts[MAX_DIRTY_TTS];				// (cylinder << 1) | head
unsigned char floppy3_dirty_tts[MAX_DIRTY_TTS];				// (cylinder << 1) | head
volatile int floppy0_dirty_tt_wi = 0;
volatile int floppy1_dirty_tt_wi = 0;
volatile int floppy2_dirty_tt_wi = 0;
volatile int floppy3_dirty_tt_wi = 0;
volatile int floppy0_dirty_tt_ri = 0;
volatile int floppy1_dirty_tt_ri = 0;
volatile int floppy2_dirty_tt_ri = 0;
volatile int floppy3_dirty_tt_ri = 0;

inline void sdram_enter_low_power_mode()
{
	fmc_sdram_self_refresh();
	GPIOC->BSRR = 1 << LED_GREEN;
}

inline void sdram_exit_low_power_mode()
{
	timer1 = SDRAM_IDLE_TIME;
	GPIOC->BSRR = 0x10000 << LED_GREEN;
}

void select_mfm_track()
{
	int head = (GPIOD->IDR & (1 << SIDE)) == 0;

	if (!FLOPPY0_SEL) {
		mfm_track = head ? mfm_track_floppy0_head1 : mfm_track_floppy0_head0;
		current_track_empty = (empty_tracks & (head ? EMPTY_TRACK_MASK_FLOPPY0_HEAD1 : EMPTY_TRACK_MASK_FLOPPY0_HEAD0)) != 0;
	} else if (!FLOPPY1_SEL) {
		mfm_track = head ? mfm_track_floppy1_head1 : mfm_track_floppy1_head0;
		current_track_empty = (empty_tracks & (head ? EMPTY_TRACK_MASK_FLOPPY1_HEAD1 : EMPTY_TRACK_MASK_FLOPPY1_HEAD0)) != 0;
#if VERSION != 0
	} else if (!FLOPPY2_SEL) {
		mfm_track = head ? mfm_track_floppy2_head1 : mfm_track_floppy2_head0;
		current_track_empty = (empty_tracks & (head ? EMPTY_TRACK_MASK_FLOPPY2_HEAD1 : EMPTY_TRACK_MASK_FLOPPY2_HEAD0)) != 0;
	} else {
		mfm_track = head ? mfm_track_floppy3_head1 : mfm_track_floppy3_head0;
		current_track_empty = (empty_tracks & (head ? EMPTY_TRACK_MASK_FLOPPY3_HEAD1 : EMPTY_TRACK_MASK_FLOPPY3_HEAD0)) != 0;
#endif
	}
}

inline void start_index_pulse()
{
	GPIOG->BSRR = 0x10000 << INDEX;
	TIM3->CNT = 0;
	TIM3->CR1 = TIM_CR1_CEN;
}

inline void stop_index_pulse()
{
	GPIOG->BSRR = 1 << INDEX;
	TIM3->CR1 = 0;
}

void TIM3_IRQHandler()
{
	TIM3->SR = 0;
	stop_index_pulse();
}

inline void wrap_mfm_offset()
{
	if (++mfm_offset == RAW_TRACK_SIZE) {
		mfm_offset = 0;
		start_index_pulse();
	}
}

inline void next_mfm_bit()
{
	if (mfm_bitmask == 1) {
		mfm_bitmask = 0x80000000;
		current_mfm_long = mfm_track[mfm_offset];
		wrap_mfm_offset();
	} else {
		mfm_bitmask >>= 1;
	}
}

void TIM4_IRQHandler()
{
	int k;

	TIM4->SR = 0;

	if (mfm_break) {
		// Stop sending track data
		TIM4->CCMR1 = 4 << TIM_CCMR1_OC1M_Pos;			// Force inactive level
		TIM4->CR1 = 0;
		if (mfm_break == 2) {
			TIM5->EGR = TIM_EGR_UG;				// Trigger immediate track sending
		}
		mfm_break = 0;
		GPIOD->BSRR = 1 << LED_YELLOW;
	} else {
		// Skip '1' bit
		next_mfm_bit();

		// Count '0' bits
		for (k = 0; !(current_mfm_long & mfm_bitmask); k++) {
			next_mfm_bit();
		}
		TIM4->ARR = dkrd_tim_arr_lut[k];
	}
}

void decode_bit(unsigned int bit)
{
	static unsigned int *odd_lword;
	static unsigned int *even_lword;
	static unsigned int info;

	current_mfm_long = (current_mfm_long << 1) | bit;
	mfm_bitcount++;

	if (mfm_bitcount == 32) {
		mfm_track[mfm_offset] = current_mfm_long;
		wrap_mfm_offset();
	}

	switch (mfm_decode_state) {
		case SYNC_WORD:
			if (current_mfm_long == 0x44894489) {
				mfm_decode_state = INFO_ODD;
				mfm_bitcount = 0;
				received_sectors++;
			}
			break;
		case INFO_ODD:
			if (mfm_bitcount == 32) {
				mfm_decode_state = INFO_EVEN;
				mfm_bitcount = 0;
				info = (current_mfm_long & 0x55555555) << 1;
			}
			break;
		case INFO_EVEN:
			if (mfm_bitcount == 32) {
				mfm_decode_state = LABEL_ODD;
				mfm_bitcount = 0;
				info |= current_mfm_long & 0x55555555;
				odd_lword = even_lword = (unsigned int *) &written_track_start[((info >> 8) & 0xff) << (9-2)];
			}
			break;
		case LABEL_ODD:
			if (mfm_bitcount == 4*32) {
				mfm_decode_state = LABEL_EVEN;
				mfm_bitcount = 0;
			}
			break;
		case LABEL_EVEN:
			if (mfm_bitcount == 4*32) {
				mfm_decode_state = HDR_CHECKSUM_ODD;
				mfm_bitcount = 0;
			}
			break;
		case HDR_CHECKSUM_ODD:
			if (mfm_bitcount == 32) {
				mfm_decode_state = HDR_CHECKSUM_EVEN;
				mfm_bitcount = 0;
			}
			break;
		case HDR_CHECKSUM_EVEN:
			if (mfm_bitcount == 32) {
				mfm_decode_state = DATA_CHECKSUM_ODD;
				mfm_bitcount = 0;
			}
			break;
		case DATA_CHECKSUM_ODD:
			if (mfm_bitcount == 32) {
				mfm_decode_state = DATA_CHECKSUM_EVEN;
				mfm_bitcount = 0;
			}
			break;
		case DATA_CHECKSUM_EVEN:
			if (mfm_bitcount == 32) {
				mfm_decode_state = DATA_ODD;
				mfm_bitcount = 0;
			}
			break;
		case DATA_ODD:
			if (mfm_bitcount && ((mfm_bitcount & 31) == 0)) {
				*odd_lword++ = __REV((current_mfm_long & 0x55555555) << 1);
			}
			if (mfm_bitcount == 512/4*32) {
				mfm_decode_state = DATA_EVEN;
				mfm_bitcount = 0;
			}
			break;
		case DATA_EVEN:
			if (mfm_bitcount && ((mfm_bitcount & 31) == 0)) {
				*even_lword++ |= __REV(current_mfm_long & 0x55555555);
			}
			if (mfm_bitcount == 512/4*32) {
				mfm_decode_state = SYNC_WORD;
				mfm_bitcount = 0;
			}
			break;
	}
}

void decode_raw_bit(unsigned int bit)
{
	current_mfm_long = (current_mfm_long << 1) | bit;
	if (++mfm_bitcount == 32) {
		mfm_bitcount = 0;
		mfm_track[mfm_offset] = current_mfm_long;
		written_track_start[mfm_offset] = __REV(current_mfm_long);
		wrap_mfm_offset();
	}
}

void TIM8_CC_IRQHandler()
{
	int k;
	unsigned short ccr1 = TIM8->CCR1;

	if (ccr1 < (TIM8_FREQ * 5 / 1000000)) {
		// 4 us - '10'
		k = 2;
	} else if (ccr1 < (TIM8_FREQ * 7 / 1000000)) {
		// 6 us - '100'
		k = 3;
	} else {
		// 8 us - '1000'
		k = 4;
	}
	if (mfm_track_type) {			// Raw track
		decode_raw_bit(1);
		while (--k) {
			decode_raw_bit(0);
		}
	} else {				// ADF track
		decode_bit(1);
		while (--k) {
			decode_bit(0);
		}
	}
}

void wait_us(int us)
{
	// assume 10 us period
	timer0 = us / 10;
	while (timer0);
}

void wait_ms(int ms)
{
	// assume 100 us period
	timer0 = ms * 10;
	while (timer0);
}

void TIM6_DAC_IRQHandler()
{
	TIM6->SR = 0;
	if (timer0) {
		timer0--;
	}
	if (timer1) {
		timer1--;
		if (!timer1) {
			sdram_enter_low_power_mode();
		}
	}
}

void TIM5_IRQHandler()
{
	TIM5->SR = 0;

	// Stop this timer
	TIM5->CR1 = 0;

	// Start sending track data
	select_mfm_track();
	mfm_break = 0;
	mfm_offset = 0;
	mfm_bitmask = 0x80000000;
	mfm_bitcount = 0;
	current_mfm_long = mfm_track[mfm_offset++];
	if (!current_track_empty) {
		TIM4->CCMR1 = 6 << TIM_CCMR1_OC1M_Pos;			// PWM mode 1 (active when CNT<CCR1)
		TIM4->CR1 = TIM_CR1_CEN;
	}
	start_index_pulse();
	GPIOD->BSRR = 0x10000 << LED_YELLOW;
}

inline void stop_sending_track_data()
{
	mfm_break = 1;
}

inline void stop_sending_track_data_now()
{
	mfm_break = 2;
}

inline void restart_send_delay_timer()
{
	TIM5->CNT = 0;
	TIM5->CR1 = TIM_CR1_CEN;
	sdram_exit_low_power_mode();
}

inline void stop_send_delay_timer()
{
	TIM5->CR1 = 0;
}

inline void exti_sel0()
{
	if (FLOPPY0_SEL) {					// rising edge
		stop_send_delay_timer();
		stop_sending_track_data();
		GPIOB->BSRR = 1 << WPROT;
		stop_index_pulse();
	} else {						// falling edge
		restart_send_delay_timer();
		mfm_track_type = (floppy_type & 0x01) != 0;
		if (floppy0_write_protected) {
			GPIOB->BSRR = 0x10000 << WPROT;
		}
	}
}

inline void exti_sel1()
{
	if (FLOPPY1_SEL) {					// rising edge
		stop_send_delay_timer();
		stop_sending_track_data();
		GPIOB->BSRR = 1 << WPROT;
		stop_index_pulse();
	} else {						// falling edge
		restart_send_delay_timer();
		mfm_track_type = (floppy_type & 0x02) != 0;
		if (floppy1_write_protected) {
			GPIOB->BSRR = 0x10000 << WPROT;
		}
	}
}

inline void exti_sel2()
{
	if (GPIOA->ODR & (1 << ENA2)) {
		if (FLOPPY2_SEL) {					// rising edge
			stop_send_delay_timer();
			stop_sending_track_data();
			GPIOB->BSRR = 1 << WPROT;
			stop_index_pulse();
		} else {						// falling edge
			restart_send_delay_timer();
			mfm_track_type = (floppy_type & 0x04) != 0;
			if (floppy2_write_protected) {
				GPIOB->BSRR = 0x10000 << WPROT;
			}
		}
	}
}
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
int main()
{
	State rx_state = NOP;
	int floppy0_encoded_cylinder = -1;
	int floppy1_encoded_cylinder = -1;
	int floppy2_encoded_cylinder = -1;
	int floppy3_encoded_cylinder = -1;
	char rx_buffer[64];
	char tx_buffer[64];
	unsigned char *floppy_fill_ptr = (unsigned char *) -1;
	unsigned int tt = 0xffffffff;
	int track_size;
	char *tx_ptr = 0;
	char *tx_end = 0;
	int tx_pending = 0;
	int wifi_setup = 0;
	int c = 0;
	int i;

	RCC->AHB1ENR |= RCC_AHB1ENR_GPIOAEN | RCC_AHB1ENR_GPIOBEN | RCC_AHB1ENR_GPIOCEN |
			RCC_AHB1ENR_GPIODEN | RCC_AHB1ENR_GPIOEEN | RCC_AHB1ENR_GPIOFEN |
			RCC_AHB1ENR_GPIOGEN | RCC_AHB1ENR_CRCEN;

	// Setup LEDs
	setup_pin(C, LED_RED, 1, 0, 0);
	setup_pin(C, LED_BLUE, 1, 0, 0);
	setup_pin(C, LED_GREEN, 1, 0, 0);
	setup_pin(D, LED_YELLOW, 1, 0, 0);

	GPIOC->BSRR = 1<<LED_RED | 1<<LED_BLUE | 1<<LED_GREEN;
	GPIOD->BSRR = 1<<LED_YELLOW;

	// Setup clocks
	RCC->CR |= RCC_CR_HSEON;
	while (!(RCC->CR & RCC_CR_HSERDY));
	RCC->PLLCFGR = 15 << RCC_PLLCFGR_PLLQ_Pos | 0 << RCC_PLLCFGR_PLLP_Pos | RCC_PLLCFGR_PLLSRC |
		       160 << RCC_PLLCFGR_PLLN_Pos | 4 << RCC_PLLCFGR_PLLM_Pos;
	RCC->CR |= RCC_CR_PLLON;
	while (!(RCC->CR & RCC_CR_PLLRDY));
	FLASH->ACR = FLASH_ACR_DCEN | FLASH_ACR_ICEN | FLASH_ACR_PRFTEN | FLASH_ACR_LATENCY_5WS;
	while ((FLASH->ACR & FLASH_ACR_LATENCY_Msk) != FLASH_ACR_LATENCY_5WS);
	RCC->CFGR = RCC_CFGR_PPRE2_DIV2 | RCC_CFGR_PPRE1_DIV4 | RCC_CFGR_HPRE_DIV1 | RCC_CFGR_SW_PLL;
	while ((RCC->CFGR & RCC_CFGR_SWS_Msk) != RCC_CFGR_SWS_PLL);

	// Setup ESP8266 communication pins
	setup_pin(G, SREQ, 1, 1, 0);
	setup_pin(E, ESP_CS, 2, 2, 5);
	setup_pin(E, ESP_CLK, 2, 2, 5);
	setup_pin(E, ESP_MISO, 2, 2, 5);
	setup_pin(E, ESP_MOSI, 2, 2, 5);

	// Setup floppy pins
	setup_pin(A, ENA3, 1, 1, 0);
	setup_pin(A, ENA2, 1, 1, 0);
	setup_pin(A, FLOP1_TRK0, 1, 1, 0);
	setup_pin(A, FLOP2_TRK0, 1, 1, 0);
	setup_pin(B, FLOP3_TRK0, 1, 1, 0);
	setup_pin(B, WPROT, 1, 1, 0);
	setup_pin(B, DIR, 0, 0, 0);
	setup_pin(C, ENA0, 1, 1, 0);
	setup_pin(C, ENA1, 1, 1, 0);
	setup_pin(C, FLOP0_TRK0, 1, 1, 0);
	setup_pin(D, SEL2, 0, 0, 0);
	setup_pin(D, SEL3, 0, 0, 0);
	setup_pin(D, SIDE, 0, 0, 0);
	setup_pin(D, DKWEB, 0, 0, 0);
	setup_pin(G, INDEX, 1, 2, 0);
	setup_pin(G, SEL0, 0, 0, 0);
	setup_pin(G, SEL1, 0, 0, 0);
	setup_pin(G, STEP, 0, 0, 0);

	GPIOB->BSRR = 1 << WPROT | 1 << FLOP3_TRK0;
	GPIOC->BSRR = 0x10000 << ENA0 | 0x10000 << ENA1 | 1 << FLOP0_TRK0;
	GPIOA->BSRR = 1 << FLOP1_TRK0 | 1 << FLOP2_TRK0 | 0x10000 << ENA2 | 0x10000 << ENA3;

	// Setup TIM12 - 10 MHz xclk
	RCC->APB1ENR |= RCC_APB1ENR_TIM12EN;
	setup_pin(B, XCLK, 2, 3, 9);					// TIM12_CH2
	TIM12->ARR = TIM_PCLK1 / TIM12_FREQ - 1;
	TIM12->CCR2 = (TIM_PCLK1 / TIM12_FREQ) / 2;
	TIM12->CCER = TIM_CCER_CC2E;
	TIM12->CCMR1 = 6 << TIM_CCMR1_OC2M_Pos;
	TIM12->CR1 = TIM_CR1_CEN;

	// Setup TIM5 - send delay
	RCC->APB1ENR |= RCC_APB1ENR_TIM5EN;
	TIM5->PSC = TIM_PCLK1 / TIM5_FREQ - 1;
	TIM5->ARR = TIM5_FREQ * READ_DELAY_US / 1000000 - 1;
	TIM5->DIER = TIM_DIER_UIE;
	NVIC_EnableIRQ(TIM5_IRQn);

	// Setup TIM6 - 10 us timer
	RCC->APB1ENR |= RCC_APB1ENR_TIM6EN;
	TIM6->PSC = TIM_PCLK1 / TIM6_FREQ - 1;
	TIM6->ARR = TIM6_FREQ / 100000 - 1;
	TIM6->DIER = TIM_DIER_UIE;
	TIM6->SR = 0;
	TIM6->CR1 = TIM_CR1_CEN;
	NVIC_EnableIRQ(TIM6_DAC_IRQn);

	// Setup TIM3 - INDEX pulse timer (2.5 ms pulse width)
	RCC->APB1ENR |= RCC_APB1ENR_TIM3EN;
	TIM3->PSC = TIM_PCLK1 / TIM3_FREQ - 1;
	TIM3->ARR = TIM3_FREQ / 400 - 1;
	TIM3->DIER = TIM_DIER_UIE;
	TIM3->SR = 0;
	TIM3->CR1 = TIM_CR1_CEN;
	NVIC_EnableIRQ(TIM3_IRQn);

	// Setup FMC
	RCC->AHB3ENR |= RCC_AHB3ENR_FMCEN;
	setup_pin(B, SDCKE1, 2, 3, 12);
	setup_pin(B, SDNE1, 2, 3, 12);
	setup_pin(C, SDNWE, 2, 3, 12);
	setup_pin(D, SD_D2, 2, 3, 12);
	setup_pin(D, SD_D3, 2, 3, 12);
	setup_pin(D, SD_D13, 2, 3, 12);
	setup_pin(D, SD_D14, 2, 3, 12);
	setup_pin(D, SD_D15, 2, 3, 12);
	setup_pin(D, SD_D0, 2, 3, 12);
	setup_pin(D, SD_D1, 2, 3, 12);
	setup_pin(E, NBL0, 2, 3, 12);
	setup_pin(E, NBL1, 2, 3, 12);
	setup_pin(E, SD_D4, 2, 3, 12);
	setup_pin(E, SD_D5, 2, 3, 12);
	setup_pin(E, SD_D6, 2, 3, 12);
	setup_pin(E, SD_D7, 2, 3, 12);
	setup_pin(E, SD_D8, 2, 3, 12);
	setup_pin(E, SD_D9, 2, 3, 12);
	setup_pin(E, SD_D10, 2, 3, 12);
	setup_pin(E, SD_D11, 2, 3, 12);
	setup_pin(E, SD_D12, 2, 3, 12);
	setup_pin(F, SD_A0, 2, 3, 12);
	setup_pin(F, SD_A1, 2, 3, 12);
	setup_pin(F, SD_A2, 2, 3, 12);
	setup_pin(F, SD_A3, 2, 3, 12);
	setup_pin(F, SD_A4, 2, 3, 12);
	setup_pin(F, SD_A5, 2, 3, 12);
	setup_pin(F, SDNRAS, 2, 3, 12);
	setup_pin(F, SD_A6, 2, 3, 12);
	setup_pin(F, SD_A7, 2, 3, 12);
	setup_pin(F, SD_A8, 2, 3, 12);
	setup_pin(F, SD_A9, 2, 3, 12);
	setup_pin(G, SD_A10, 2, 3, 12);
	setup_pin(G, SD_A11, 2, 3, 12);
	setup_pin(G, BA0, 2, 3, 12);
	setup_pin(G, BA1, 2, 3, 12);
	setup_pin(G, SDNCLK, 2, 3, 12);
	setup_pin(G, SDNCAS, 2, 3, 12);
	fmc_sdram_init();

	// Re-setup TIM6 - 100 us timer
	TIM6->ARR = TIM6_FREQ / 10000 - 1;

	// Setup TIM4 - MFM signal generator
	RCC->APB1ENR |= RCC_APB1ENR_TIM4EN;
	setup_pin(D, DKRD, 2, 2, 2);					// TIM4_CH1
	TIM4->PSC = TIM_PCLK1 / TIM4_FREQ - 1;
	TIM4->ARR = dkrd_tim_arr_lut[0];
	TIM4->CCR1 = 1;
	TIM4->CCER = TIM_CCER_CC1P | TIM_CCER_CC1E;
	TIM4->DIER = TIM_DIER_UIE;
	TIM4->CCMR1 = 4 << TIM_CCMR1_OC1M_Pos;				// Force inactive level
	TIM4->CCMR1 = 6 << TIM_CCMR1_OC1M_Pos;				// PWM mode 1 (active when CNT<CCR1)
	NVIC_EnableIRQ(TIM4_IRQn);

	// Setup TIM8 - MFM signal scanner
	RCC->APB2ENR |= RCC_APB2ENR_TIM8EN;
	setup_pin(C, DKWDB, 2, 0, 3);					// TIM8_CH1
	TIM8->ARR = 0xffff;
	TIM8->PSC = TIM_PCLK2 / TIM8_FREQ - 1;
	TIM8->SMCR = (5 << TIM_SMCR_TS_Pos) | (4 << TIM_SMCR_SMS_Pos);
	TIM8->CCMR1 = 1 << TIM_CCMR1_CC1S_Pos;				// IC1 -> TI1
	TIM8->CCER = TIM_CCER_CC1P | TIM_CCER_CC1E;			// TI1FP1 falling edge
	TIM8->DIER = TIM_DIER_CC1IE;
	NVIC_EnableIRQ(TIM8_CC_IRQn);

	// Setup EXTI interrupts (SEL0:G3, SEL1:G6, SEL2:D4, SEL3:D5, STEP:G7, SIDE:D11, DKWEB:D13)
	RCC->APB2ENR |= RCC_APB2ENR_SYSCFGEN;
	SYSCFG->EXTICR[0] = 0x6000;		// PG3
	SYSCFG->EXTICR[1] = 0x6633;		// PG7, PG6, PD5, PD4
	SYSCFG->EXTICR[2] = 0x3000;		// PD11
	SYSCFG->EXTICR[3] = 0x0030;		// PD13
	EXTI->IMR = (1 << SEL0) | (1 << SEL1) | (1 << STEP) | (1 << DKWEB) | (1 << SIDE) | EXTI_SEL23_MSK;
	EXTI->RTSR = (1 << SEL0) | (1 << SEL1) | (1 << STEP) | (1 << DKWEB) | (1 << SIDE) | EXTI_SEL23_MSK;
	EXTI->FTSR = (1 << SEL0) | (1 << SEL1) | (1 << DKWEB) | (1 << SIDE) | EXTI_SEL23_MSK;
	NVIC_EnableIRQ(EXTI3_IRQn);
	NVIC_EnableIRQ(EXTI4_IRQn);
	NVIC_EnableIRQ(EXTI9_5_IRQn);
	NVIC_EnableIRQ(EXTI15_10_IRQn);

	// Test SDRAM
	for (i = 0; i < 8*1048576/4; i++) {
		floppy0_data[i] = i;
	}
	for (i = 0; i < 8*1048576/4; i++) {
		if (floppy0_data[i] != i) {
			break;
		}
	}
	if (i < 8*1048576/4) {
		// Blink green LED on SDRAM error
		while (1) {
			GPIOC->ODR ^= 1 << LED_GREEN;
			for (i = 0; i < 20000000; i++) {
				asm ("nop\n\t");
			}
		}
	}

	// Setup DMA2 & SPI4 - ESP8266 communication
	RCC->AHB1ENR |= RCC_AHB1ENR_DMA2EN;
	RCC->APB2ENR |= RCC_APB2ENR_SPI4EN;
	SPI4->CR2 = SPI_CR2_TXDMAEN | SPI_CR2_RXDMAEN;
	SPI4->CR1 = SPI_CR1_SPE;

	// Prepare track buffers
	for (i = MFM_TRACK_SIZE; i < MFM_TRACK_SIZE+MFM_GAP_SIZE; i++) {
		mfm_track_floppy0_head0[i] = 0xaaaaaaaa;
		mfm_track_floppy0_head1[i] = 0xaaaaaaaa;
		mfm_track_floppy1_head0[i] = 0xaaaaaaaa;
		mfm_track_floppy1_head1[i] = 0xaaaaaaaa;
		mfm_track_floppy2_head0[i] = 0xaaaaaaaa;
		mfm_track_floppy2_head1[i] = 0xaaaaaaaa;
		mfm_track_floppy3_head0[i] = 0xaaaaaaaa;
		mfm_track_floppy3_head1[i] = 0xaaaaaaaa;
	}

	GPIOC->BSRR = 0x10000 << LED_GREEN;
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

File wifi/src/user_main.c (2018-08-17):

/*
 * phloppy_0 - Commodore Amiga floppy drive emulator
 * Copyright (C) 2016-2018 Piotr Wiszowaty
 *
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
 * You should have received a copy of the GNU General Public License
 * along with this program.  If not, see <http://www.gnu.org/licenses/>.
 */

#include <osapi.h>
#include <user_interface.h>
#include <gpio.h>
#include <espconn.h>
#include "wifi_parameters.h"

#define MAX_CONNECTIONS	1

#define MAIN_PORT	4500
#define AUX_PORT	4501

#define MREQ	(1 << 4)
#define SREQ	(1 << 5)

struct espconn aux_conn;
esp_tcp aux_tcp;
struct espconn main_conn;
esp_tcp main_tcp;

char aux_buffer[80];
int aux_offset = 0;
char main_buffer[8192];
int main_rx_ri;
int main_rx_wi;
int main_tx_i;
char tx_blocked;

uint32 ICACHE_FLASH_ATTR
user_rf_cal_sector_set()
{
	switch (system_get_flash_size_map()) {
		case FLASH_SIZE_4M_MAP_256_256:
			return 128 - 5;
		case FLASH_SIZE_8M_MAP_512_512:
			return 256 - 5;
		case FLASH_SIZE_16M_MAP_512_512:
		case FLASH_SIZE_16M_MAP_1024_1024:
			return 512 - 5;
		case FLASH_SIZE_32M_MAP_512_512:
		case FLASH_SIZE_32M_MAP_1024_1024:
			return 1024 - 5;
		default:
			return 0;
	}
}

void
spi_txrx(char *buffer)
{
	gpio_output_set(MREQ, 0, 0, 0);
	while (!(GPIO_REG_READ(GPIO_IN_ADDRESS) & SREQ));
	spi_transaction(buffer, 64);
	gpio_output_set(0, MREQ, 0, 0);
	while (GPIO_REG_READ(GPIO_IN_ADDRESS) & SREQ);
}

void ICACHE_FLASH_ATTR
aux_recv_cb(void *arg, char *data, unsigned short length)
{
	struct espconn *conn = arg;

	if (data != NULL) {
		while (length--) {
			aux_buffer[aux_offset++ % sizeof(aux_buffer)] = *data++;
		}
	}
}

void ICACHE_FLASH_ATTR
aux_disconnect_cb(void *arg)
{
	struct espconn *conn = arg;

	os_printf("AUX disconnect %d.%d.%d.%d:%d\r\n", conn->proto.tcp->remote_ip[0],
			conn->proto.tcp->remote_ip[1], conn->proto.tcp->remote_ip[2],
			conn->proto.tcp->remote_ip[3], conn->proto.tcp->remote_port);
}
 
void ICACHE_FLASH_ATTR
aux_connect_cb(void *arg)
{
	struct espconn *conn = arg;

	espconn_send(conn, aux_buffer, sizeof(aux_buffer));
	aux_offset = 0;

	espconn_regist_recvcb(conn, aux_recv_cb);
	espconn_regist_disconcb(conn, aux_disconnect_cb);

	os_printf("AUX connect %d.%d.%d.%d:%d\r\n", conn->proto.tcp->remote_ip[0],
			conn->proto.tcp->remote_ip[1], conn->proto.tcp->remote_ip[2],
			conn->proto.tcp->remote_ip[3], conn->proto.tcp->remote_port);
}

sint8
comm_main(struct espconn *conn)
{
	sint8 result = 0;
	int i;

	while (main_tx_i != main_rx_ri) {
		if (main_buffer[main_tx_i]) {
			//os_printf("tx:%d\r\n", main_tx_i);
			result = espconn_send(conn, main_buffer + main_tx_i + 1, 63);
			if (result < 0) {
				break;
			} else {
				/*
				for (i = 0; i < 64; i++) {
					os_printf("%02x ", main_buffer[main_tx_i + i]);
				}
				os_printf("\r\n");
				*/
				main_tx_i = (main_tx_i + 64) & (sizeof(main_buffer) - 1);
			}
		} else {
			main_tx_i = (main_tx_i + 64) & (sizeof(main_buffer) - 1);
		}
	}
	return result;
}

int
abs(int x)
{
	return x < 0 ? -x : x;
}

void
main_recv_cb(void *arg, char *data, unsigned short length)
{
	struct espconn *conn = arg;
	sint8 result;

	if (data == NULL) {
		return;
	}

	while (length--) {
		main_buffer[main_rx_wi++] = *data++;
		main_rx_wi &= sizeof(main_buffer) - 1;
		if (abs(main_rx_wi - main_rx_ri) >= 64) {
			spi_txrx(main_buffer + main_rx_ri);
			main_rx_ri = (main_rx_ri + 64) & (sizeof(main_buffer) - 1);
			//os_printf("rx:%d\r\n", main_rx_ri);
			if (!tx_blocked) {
				if (comm_main(conn) < 0) {
					tx_blocked = 1;
					espconn_recv_hold(conn);
					os_printf("tx:block\r\n");
				}
			}
		}
	}
}

void ICACHE_FLASH_ATTR
main_sent_cb(void *arg)
{
	struct espconn *conn = arg;

	if (comm_main(conn) == 0 && main_rx_ri == main_tx_i && tx_blocked) {
		tx_blocked = 0;
		espconn_recv_unhold(conn);
		os_printf("tx:unblock\r\n");
	}
}

void ICACHE_FLASH_ATTR
main_disconnect_cb(void *arg)
{
	struct espconn *conn = arg;

	os_printf("MAIN disconnect %d.%d.%d.%d:%d\r\n", conn->proto.tcp->remote_ip[0],
			conn->proto.tcp->remote_ip[1], conn->proto.tcp->remote_ip[2],
			conn->proto.tcp->remote_ip[3], conn->proto.tcp->remote_port);
}
 
void ICACHE_FLASH_ATTR
main_connect_cb(void *arg)
{
	struct espconn *conn = arg;

	main_rx_ri = 0;
	main_rx_wi = 0;
	main_tx_i = 0;
	tx_blocked = 0;

	espconn_regist_recvcb(conn, main_recv_cb);
	espconn_regist_sentcb(conn, main_sent_cb);
	espconn_regist_disconcb(conn, main_disconnect_cb);

	os_printf("MAIN connect %d.%d.%d.%d:%d\r\n", conn->proto.tcp->remote_ip[0],
			conn->proto.tcp->remote_ip[1], conn->proto.tcp->remote_ip[2],
			conn->proto.tcp->remote_ip[3], conn->proto.tcp->remote_port);
}

void ICACHE_FLASH_ATTR
user_init()
{
	struct softap_config config;
	char buffer[64];
	struct wifi_parameters *wp = (struct wifi_parameters *) (buffer + 1);
	int i;

	os_printf("Phloppy_0\r\n");

	gpio_output_set(0, MREQ, MREQ, 0);

	spi_init();
	spi_tx_byte_order(0);
	spi_rx_byte_order(0);
	os_printf("SPI initialized\r\n");

	for (i = 0; i < sizeof(buffer); i++) {
		buffer[i] = 0;
	}
	buffer[0] = 0xc0;	// END
	buffer[1] = 0x80;	// SETUP_WIFI
	buffer[2] = 0xc0;	// END
	buffer[3] = 0x00;	// NOP
	spi_txrx(buffer);
	buffer[0] = 0x00;
	buffer[1] = 0x00;
	buffer[2] = 0x00;
	buffer[3] = 0x00;
	spi_txrx(buffer);

	os_printf("SSID: %s, passwd: %s\r\n", wp->ssid, wp->password);

	wifi_set_opmode(SOFTAP_MODE);
	bzero(&config, sizeof(config));
	strcpy(config.ssid, wp->ssid);
	strcpy(config.password, wp->password);
	config.authmode = AUTH_WPA_WPA2_PSK;
	config.ssid_len = 0;
	config.max_connection = 2;
	wifi_softap_set_config(&config);

	os_printf("WiFi initialized\r\n");

	bzero(&main_conn, sizeof(struct espconn));
	bzero(&main_tcp, sizeof(esp_tcp));
	main_tcp.local_port = MAIN_PORT;
	main_conn.type = ESPCONN_TCP;
	main_conn.state = ESPCONN_NONE;
	main_conn.proto.tcp = &main_tcp;
	espconn_regist_connectcb(&main_conn, main_connect_cb);
	i = espconn_accept(&main_conn);
	os_printf("MAIN accept %d\r\n", i);

	bzero(aux_buffer, sizeof(aux_buffer));

	bzero(&aux_conn, sizeof(struct espconn));
	bzero(&aux_tcp, sizeof(esp_tcp));
	aux_tcp.local_port = AUX_PORT;
	aux_conn.type = ESPCONN_TCP;
	aux_conn.state = ESPCONN_NONE;
	aux_conn.proto.tcp = &aux_tcp;
	espconn_regist_connectcb(&aux_conn, aux_connect_cb);
	i = espconn_accept(&aux_conn);
	os_printf("AUX accept %d\r\n", i);
}

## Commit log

2018-08-17 Add sources
    [phloppy_0.kicad_pcb, phloppy_0.sch]
2018-08-17 pcb: Update gitignore
2018-08-17 pcb: Add OSHW symbol
    [phloppy_0.kicad_pcb]
2018-08-17 Add compilation output and Gerber files
    [phloppy_0-B.Cu.gbr, phloppy_0-B.Mask.gbr, phloppy_0-B.SilkS.gbr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]
2018-08-18 Add photos of the device

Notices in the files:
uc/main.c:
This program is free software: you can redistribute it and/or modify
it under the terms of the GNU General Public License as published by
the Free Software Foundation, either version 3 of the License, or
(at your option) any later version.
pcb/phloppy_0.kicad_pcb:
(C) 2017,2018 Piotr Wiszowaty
